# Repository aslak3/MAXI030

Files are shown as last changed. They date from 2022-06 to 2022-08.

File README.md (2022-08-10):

# MAXI030: a MC68030 based expandable computer

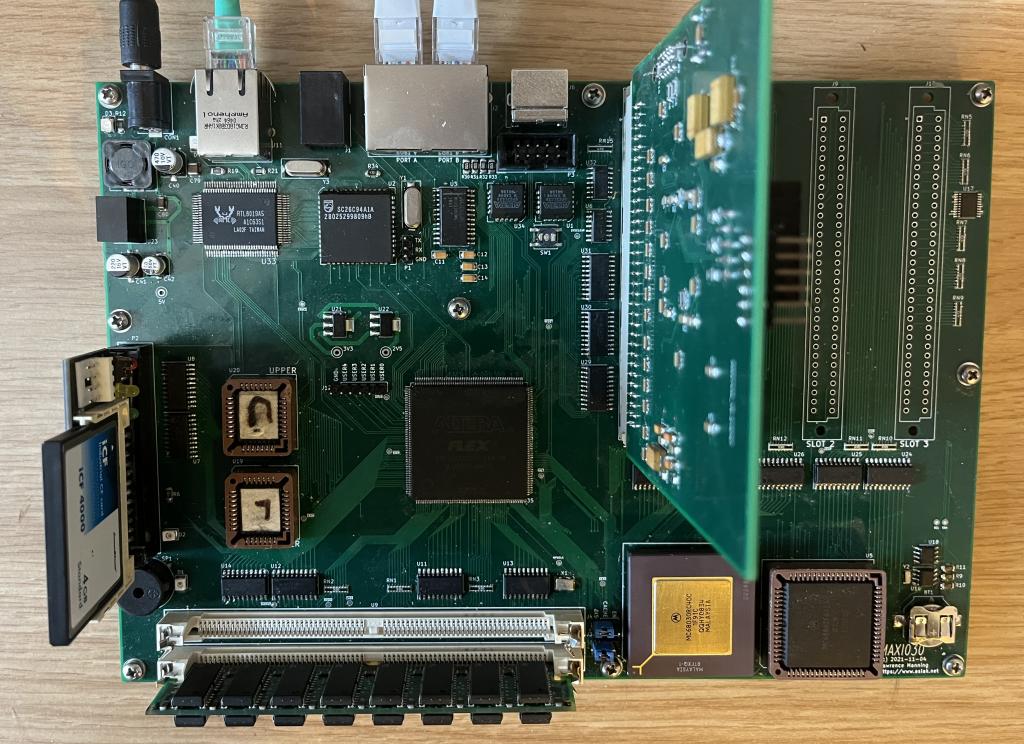
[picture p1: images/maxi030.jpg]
MAXI030 PCB


## Features as currently implemented

The specification for MAXI030, a [MC68030](https://www.nxp.com/docs/en/reference-manual/MC68030UM.pdf) based computer, is as follows:

* A core "glue" that is wired to [master](https://en.wikipedia.org/wiki/Bus_mastering) the 32 bit busses
* Glue is provided by an [EPF10K130EQC240-1](https://www.micro-semiconductor.com/datasheet/12-EPF10K100EFC256-2AA.pdf) FPGA
* A 68030 coupled with a [68882](https://www.nxp.com/docs/en/data-sheet/BR509.pdf)
* 512K x 16 flashes in the form of 2 x [SST39SF040](http://ww1.microchip.com/downloads/en/DeviceDoc/20005022C.pdf) in PLCC32
* 2 x [72 pin SIMM](https://en.wikipedia.org/wiki/SIMM#72-pin_SIMMs) slots with a controller implemented in the FPGA
* A [SC26C94](https://pdf.dzsc.com/6C9/SC26C94.pdf) QUART with the following arrangements of the four serial ports:
  * Two on RJ45 at RS-232 levels following the standard Cisco pinnout
  * One for [my Amiga 600 keyboard](https://www.aslak.net/index.php/amiga-600-avr-based-keyboard-controller/) on an RJ11
  * And a TTL header for debug and the bring-up
* Onboard 10Mbit/s Ethernet using a [RTL8019AS](http://www.ethernut.de/pdf/8019asds.pdf)
* A [PS/2](https://en.wikipedia.org/wiki/PS/2_port) port for keyboard and mouse using a splitter cable
* Four 16 bit wide by 16 MByte deep expansion slots compatible with cards like my [video card](https://www.aslak.net/index.php/2021/07/08/the-design-of-a-video-and-sound-card-for-midi020/) which was implemented for my earlier MC68020 board
* I2C bus with:
  * [DS13057](https://datasheets.maximintegrated.com/en/ds/DS1307.pdf) RTC
  * [LM75A](https://www.nxp.com/docs/en/data-sheet/LM75A.pdf) temperature sensor
  * [PCA9544APW](https://www.nxp.com/docs/en/data-sheet/PCA9544A.pdf) four way expansion slot bus multiplexer allowing expansion cards to attach to the I2C bus
* [IDE](https://en.wikipedia.org/wiki/Parallel_ATA) with DMA signals routed to the FPGA, though they are currently not utilised
* A [P7805-2000-S](https://www.mouser.co.uk/datasheet/2/670/p78_2000_s-1729053.pdf) 2A 5V potted switching regulator attached to a barrel jack

A [schematic](MAXI030.pdf) is included here, along with the [KiCAD](https://www.kicad.org) data files. Note that schematic symbols are included in the library cache. Whilst these boards were designed with KiCAD 4, the files in this repository are all KiCAD 6 format.

## PCB design

The PCB is a 4 layer board. The requirements to make the board are quite heavy; 6 mil traces are used, with 6.5 mil clearances between them. 3 traces pass between 100mil spaced pins in multiple places. My boards were manufactured by [JLCPCB](https://www.jlcpcb.com) with no issues.

## Glue logic core

A major feature of this board is the EPF10K130EQC240 FPGA. This component is part of Altera's [Flex 10KE](https://www.micro-semiconductor.com/datasheet/12-EPF10K100EFC256-2AA.pdf) family, which is a 3.3V/2.5V part descended from the [Flex 10K](https://www.dexsilicium.com/altera_flex_epf10k.pdf) line of 5V parts. These FPGAs are unfortunately obsolete, and difficult to get hold of; I sourced mine from [UTSource](https://www.utsource.net).

The board uses mixed 3.3V and 5V signaling. The Flex 10KE series is "special" in that it is fully 5V tolerant without an inline resistor, unlike later Altera parts such as the early Cylcones which are 5V tolerant but need an inline resistor. The Flex 10KE also have outputs compatible with 5V TTL levels. My previous projects have made heavy use of the 5V Flex 10K parts, but I have found that as the board frequency has increased, these FPGAs have reached their limit. Consequently this board switched to the Flex 10KE, despite the complexities inherent in a mixed signal level board.

Beside getting hold of the actual part a challenge facing anyone building this board is obtaining a compatible Altera Quartus version since Intel have, in their wisdom, removed from their site the 9.0sp2 version; the last that supported the Flex 10K(E) series. It can still be obtained if you know where to look, however.

Another small annoyance, related to the FPGA side of the board, is that two EPC2 configuration flashes are needed since this is a large, for the time, FPGA.

I have implemented the following functionality, all in VHDL:

* Core glue, address decoding etc
* A basic DRAM controller for one of the SIMM slots
* Buzzer and LED driver
* Simplistic interrupt routing (autovectored only for now)
* An I2C master to operate the RTC and temperature sensor
* A PS/2 controller for both PS/2 connections
* An SPI output channel, and bi-directional UART, both for debugging

The code for this functionality resides in the [MAXI030Core directory](MAXI030Core), where a more detailed description of the files used can be found.

As this is FPGA hardware, many other things could be implemented. In particular, the FPGA is wired to the full 32 bits of address and data, so a bus-mastering DMA controller could be constructed. This could be used for disk transfers, amongst other things, which would greatly speed up these operations. The interrupt handling is also basic at present, and vectored interrupts should probably be used.

It's worth pointing out, for completeness, that since the FPGA is attached to a 32 bit wide by 4GB address space it would theoretically be possible to use this board to replace the 68030 with some other custom softcore processor running inside the FPGA, with the 68030 disabled or simply not present. Perhaps a more interesting opportunity would be to implement a custom 68020+ style co-processor.

## Expansion Cards

The following three cards have been created:

1. [TestSRAM](ExpansionCards/TestSRAM/) - This is card is only really useful for the bringup. It has two 512KB SRAMs attached, along with pin headers attached to he expansion bus. It allows the system to be used without having a SIMM attached (and working).
2. [Printer+Sticks](ExpansionCards/Printer%2BSticks/) - This is a fairly simple card featuring a [MC68230](http://www.ceipsa.com/datasheet/MC68230.pdf) and some latches. The board does not feature a DB25 connector, instead the printer must be attached through a "standard" 2x13 PC style adapter. The latches are attached to DB9 Atari-style joystick ports.
3. [Video+Sound](ExpansionCards/Video%2BSound/) - The most interesting card by far; this a VGA card implemented with a Cyclone II FPGA and some fast 16 bit SRAM to hold the video framebuffer. Also featured is an I2S DAC.

The TestxSRAM card (such as it is) has been shown to be error-free. The Printer+Joystick card has been exercised by attaching an old 9 pin dot matrix printer and printing text, though this was with the earlier MIDI020 68020 board. The Video+Sound board has been attached to MAXI030 and, though it has a few teaming troubles, it appears to work well. The sound portion of that card has not been explored at all however.

More documentation on these cards will be forthcoming. For now, each expansion card directory contains the schematic and PCB files in KiCAD format, plus a PDF of the schematic, the BOM, and the rendered gerbers used to produce the cards.

## Machine-code monitor

Over the years I've extended my monitor to run on each 68K based board as I've produced them. The monitor is basic, but serviceable. It is in no way designed for software development; it's main purpose is to exercise the hardware. It has low-level (memory/IO operations) and high level functionality:

* IDE identify, read and write sectors
* PS/2 reading/writing
* I2C reading/writing
* And others

It is also used to start the Linux kernel.

The monitor source is held in its [own repository](https://www.github.com/aslak3/m68k-monitor).

## Linux

A Linux port has been started and seems to work quite well. The following hardware has been shown to work, by making very small changes to existing drivers or creating new ones:

* /dev/ttySC{0,1} UART ports - these map to Port A and Port B on the board
* IDE - though neither interrupt mode or DMA is currently supported so it is rather slow
* Ethernet - works well, though the transfers are on an 8 bit port
* RTC and temperature sensor - an I2C bus driver has been produced which can talk to these peripherals
* PS/2 - the driver implemented supports both ports
* Framebuffer - a very slow and Work in Progress driver for the video card I've built

With a 32MHz can installed, a modern Linux kernel will boot in about 2.5 minutes. But see the Gotchas section below.

A [fork of the Linux kernel](https://www.github.com/aslak3/linux.git) from early 2022 has work done at the head of the lm/maxi030 branch with the changes I've made.

The userland I'm currently using is based on a very old Debian build, even though the kernel is almost the latest, since running the latest 68k Debian packages results in a very slow system. This is another thing to investigate.

A script, which is a total hack, for generating an directory tree of Debian Linux is available in the [linux](linux) directory. This script can generate both sid (current) and sarge (old) Debian images. It must be edited before use to set the DNS resolver, interface addressing, passwords, custom packages and other things. It makes use of [multistrap](https://wiki.debian.org/Multistrap) and [QEUMU's 68K support](https://wiki.qemu.org/Documentation/Platforms/m68k) to do its thing.

As it currently stands, the Linux system is useable across the UART (via a login getty), and via the network. Both SSH and telnet are available, SSH being extremely slow as predicted. Console access, using the PS/2 port and my bitmap video card, is very much a work in progress, though I did have X running (very, very slowly) at one point.

The general process to get Linux running on MAXI030 is as follows, assuming the board is up and running with the monitor available via a UART port:

1. At present the MAC address of the Linux host, which will supply the image, is hardcoded into the monitor program in ne2k.c in the ne2k_transmit subroutine; change it to your PCs MAC address. Note that the MAXI030 MAC address is hardcoded to 11:22:33:44:55:66
2. Build a suitably patched kernel and convert it to a raw image
3. Modify the eth-sender program as required, at a minimum the device name for the connected ethernet interface is hardcoded
4. Run up the eth-sender program (it requires root), the kernel should be available in the same directory and called vmlinux.bin
5. Partition a Compact Flash: two partitions using MBR, partition 1 for swap and 2 for the rootfs in ext3 (ext4 will work with a newer Debian userland)
6. Modify the make-multistrap script as required
7. Create the Debian directory structure and copy it into partition two on the Compact Flash
8. Create a swap partition (mkswap) on partition one
9. Plug in the Compact Flash and turn on MAXI030
10. Transfer the kernel to MAXI030 with the linuxdl command
11. Run the kernel with a monitor command like: linuxrun "console=ttySC0,38400 root=/dev/sda2"
12. Wait for kernel to boot
13. Login via the getty, test the network etc

## Issues

The big issue I'm currently working on is board speed. With all the functionality enabled in the FPGA design, I'm currently not able to run the board at the maximum speed of the 68030 I have installed, 40MHz. Insteaed I must settle for running the board at 32MHz. In particular adding the FIFOs on the PS/2 controller results in an inoperable system at 40MHz. The FIFOs seem to be required when running in Linux since the kernel disables interrupts in some situations, which results in data loss.

The board also has a few very minor problems:

* The switching regulator footprint matches the 1A [SR10S05](https://www.xppower.com/portals/0/pdfs/SF_SR.pdf) and similar; the original 2A part fits but must hang off the board since its pinout is reversed. In use and with the video card inserted and a single SIMM attached I've rarely seen the current draw pass 500mA so I think a 1A regulator will be fine
* The silk screen labels for UART Port A and Port B are the wrong way around
* The labels for Enable/Disable on the MMU/cache jumpers are also backwards

## Blog

The best place to learn about this board is undoubtably [my blog](https://www.aslak.net/index.php/category/68k/), including these posts:

* [The design of MAXI030](https://www.aslak.net/index.php/2021/10/02/the-design-of-a-68030-based-expandable-computer/)
* [Porting Linux to the MAXI030](https://www.aslak.net/index.php/2022/01/11/porting-linux-to-the-68030-based-maxi030/)

I've also made a [short YouTube video](https://www.youtube.com/watch?v=WL3ttsiriho), which discusses the board and demos the Linux port.

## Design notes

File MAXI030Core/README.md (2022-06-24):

# MAXI030Core

The MAXI030 FPGA is responsible for essentially all the functionality that would have traditionally been included in glue logic, wether implemented with discrete logic ICs, GALs, or whatever. It also contains the logic for implementing various controllers and interfaces, which would normally be handled by external peripheral ICs, including:

* DRAM controller for the SIMM slots, including the address multiplexers
* I2C master
* PS/2 interfaces (for keyboard and mouse)
* Interrupt control
* LED and buzzer output control
* 5 pins of user-headers, generally used for debugging and board bringup

Since the FPGA is attached to the full 32 bits of the address and data busses, it is eventually intended to implement a bus-mastering DMA controller, though no progress has been made to this end.

The design also includes a debug/bringup aid in the form of an SPI output-only interface.

Currently only the top 8 bits of databus are used for communication between the processor and the FPGA. This is a result of this design being an evolution of an earlier one where this was a wiring restriction. Consequently services which require larger values to be programmed into them, like the timer, require multiple addresses. This will be eliminated when the full 32 bit databus is utilised.

Note that for consistency all internal signals use positive logic. Inputs are converted to positive logic and outputs are converted to negative logic, if needed. The n_ prefix on signal names is used to indicate negative logic.

Please note that I'm a self-taught VHDL designer. Except in rare cases, these designs do not make use of test benches.

## maxi030_core.vhd

This is the main design file and includes the following entities:

### vector_mapper

This entity deals with startup. Like most 68K based boards, a "trick" is used to map the ROM/flash into low memory only for the initial startup. After the initial Stack Pointer and Program Counter (2 longs, which needs 4 accesses to the 16 bit wide ROM) have been read in, the system enters the normal runtime mode where address decoding will utilise the runtime address map, which is described below. This is achieved by counting (with a shift register) Address Strobes edges; after 4 rising edges the vectors have been read and the system is in the normal runtime mode, indicated by a high vector_fetched output.

### addr_decode

This is the main address decoding logic. Due to various factors, this is currently implemented as a sequential block instead of the more obvious and likely correct combinational design. Partly this is because of the complexity in the memory map for the system. A combinational decoder would be very hard to write "nicely".

The address map is as follows, all addresses in hex. Note that the decoding is partial in that the selected devices will appear at many addresses not just the "official" address used by software. This saves logic resouces. Don't cares are illustrated by dashes in the table below:

<table>
<tr>
<th>Address</th>
<th>Function</th>
</tr><tr>
<td>00000000-30000000</td>
<td>SIMM slot 0</td>
</tr><tr>
<td>40000000-40ffffff</td>
<td>Expansion slot 0</td>
</tr><tr>
<td>41000000-41ffffff</td>
<td>Expansion slot 1</td>
</tr><tr>
<td>42000000-42ffffff</td>
<td>Expansion slot 2</td>
</tr><tr>
<td>43000000-43ffffff</td>
<td>Expansion slot 3</td>
</tr><tr>
<td>44--0---</td>
<td>FPGA registers</td>
</tr><tr>
<td>44--0-00</td>
<td>LED</td>
</tr><tr>
<td>44--0-01</td>
<td>BUZZER</td>
</tr><tr>
<td>44--0-02</td>
<td>SYS_CONFIG</td>
</tr><tr>
<td>44--0-03</td>
<td>PS2A_STATUS</td>
</tr><tr>
<td>44--0-04</td>
<td>PS2A_SCANCODE</td>
</tr><tr>
<td>44--0-05</td>
<td>PS2B_STATUS</td>
</tr><tr>
<td>44--0-06</td>
<td>PS2B_SCANCODE</td>
</tr><tr>
<td>44--0-07</td>
<td>I2C_ADDRESS</td>
</tr><tr>
<td>44--0-08</td>
<td>I2C_WRITE_DATA</td>
</tr><tr>
<td>44--0-09</td>
<td>I2C_READ_DATA</td>
</tr><tr>
<td>44--0-0a</td>
<td>I2C_CONTROL</td>
</tr><tr>
<td>44--0-0B</td>
<td>RTC_INT_CONTROL</td>
</tr><tr>
<td>44--0-0c</td>
<td>SPI</td>
</tr><tr>
<td>44--0-0d</td>
<td>TIMER_COUNTU</td>
</tr><tr>
<td>44--0-0e</td>
<td>TIMER_COUNTM</td>
</tr><tr>
<td>44--0-0f</td>
<td>TIMER_COUNTL</td>
</tr><tr>
<td>44--0-10</td>
<td>TIMER_CONTROL</td>
</tr><tr>
<td>44--0-11</td>
<td>INT_PASS</td>
</tr><tr>
<td>44--1---</td>
<td>QUART</td>
</tr><tr>
<td>44--2---</td>
<td>IDE1</td>
</tr><tr>
<td>44--3---</td>
<td>IDE3</td>
</tr><tr>
<td>44--4---</td>
<td>ETH</td>
</tr><tr>
<td>ff------</td>
<td>ROM</td>
</tr><tr>
</table>

The address decoder also deals with non "normal" accesses, namely:

* FPU: The coprocessor uses standard bus cycles, but with a specific Function Code output, and address outputs.
* Interrupt Acknowledgement: Similar to coprocessor access.

When not in the vector_fetched state, the address decoder is also responsible for forcing the ROM to be selected, regardless of other inputs.

Note the overlying state of a bus cycle, which is one of:

* CYCLE_NULL: set when the address strobe is not asserted
* CYCLE_BOOT_VECTORS: set for the first four address strobe cycles
* CYCLE_FPU: set when the cycle is an FPU cycle
* CYCLE_INT_ACK: set when the cycle is an interrupt acknowledgement
* CYCLE_REG: set when an FPGA register is being accessed
* CYCLE_NORMAL: set for all other accesses

This is asserted combinationally in the external entity, and is fed to the address decoder to save it somme work.

The output of the address decoder is an array, with one element per device. The address decoder will only assert one select at a time. Another key signal the address decoder is responsible for generating is the addr_width output, which sets the width of the device selected (byte, word or long). This in turn is used to generate the processor's /DSACK signals. For instance, the SIMM is a 32 bit (long) wide device, whilst the flash and expansion slots are 16 bits wide.

The following is a table for the data width of the various devices on the board:

<table>
<tr>
<th>Device</th>
<th>Width</th>
</tr><tr>
<td>SIMM</td>
<td>Long</td>
</tr><tr>
<td>ROM</td>
<td>Word</td>
</tr><tr>
<td>Expansion slots</td>
<td>Word</td>
</tr><tr>
<td>RTL8019AS (NIC)</td>
<td>Word</td>
</tr><tr>
<td>IDE</td>
<td>Word</td>
</tr><tr>
<td>QUART</td>
<td>Byte</td>
</tr><tr>
<td>Core registers</td>
<td>Byte</td>
</tr>
</table>

## dtack_generator

This entity's job is to delay the /DSACK signal for the number of cycles required for each particular device that needs this functionality. It is is fed a generic; the cycle count. A simple counter is used to assert a "wait complete" signal when the counter reaches the delay value. An instance of this entity is created for each device which needs waitstates. This is one of the few entities to have multiple instances.

## buzzer_generator

A simple tone generator. The tone to be played is generated by incrementing a counter until it reaches the programmed value, upon which the buzzer output is toggled. The upper 8 bits of the 18 bit counter are compared, to scale the tone to audible values. Setting the programmed value to zero disables forces the buzzer output low, silencing the buzzer.

## maxi030_core

This is the top level entity. It is mostly concerned with instantiating the other entities, but also has some functionality of its own.

### Port sizing

The 68030 is a 32 bit processor with a byte addressable address bus. It supports both narrowed (word and byte wide) accesses and unaligned accesses; for example a long read to a word wide port might, in the worst case, be spread across three bus cycles). This is facilitated by the following signals, from the point of view of the processor:

* SIZ{0,1} outputs: This encodes the size of the request.
* A0 and A1 outputs: This indicates the offset into the word or long.
* /DSACK{0,1} inputs: This encodes the size of the port available at the selected address, in addition to indicating that the processor should generate an internal waitstate.

To complete the access, the processor may need to generate individual byte selects. For instance, a 32 bit device, like a 72 pin SIMM, needs byte selects for each of the 4 bytes available. These outputs need to be generated based on the size of the request and the A0/A1 values for the access.

Luckily the [MC68030 datasheet](https://www.nxp.com/docs/en/reference-manual/MC68030UM.pdf) includes both a schematic including 74-series logic gates, and some [ABEL](https://en.wikipedia.org/wiki/Advanced_Boolean_Expression_Language) code for a circuit that generates the needed signals for word and long-wide devices. This ABEL code has been translated into VHDL and included verbatim. Devices use these internal signals to form their final chip selects, by combining them with the device selects generated by the address decoder.

### Cycle type generator

This was covered in the address decoding section above.

### Read and Write generator

This is a simple but critical part of the design which generates internal read and write signals, using the /DS data strobe and R/W signal. In this block the write line is also inhibited for ROM access, if the SYS_CONFIG register is configured to do this. This was useful on earlier boards which used simple EEPROMs but is less useful now that flashes, which can only be programmed by very specific command sequences, are used.

### Register Read and Write action

This sequential process is responsible for managing internal state based on accesses by the processor to FPGA-exposed registers. For instance, the board LED is controlled by the processor writing to the low bit of the LED register's address (generally 44000001). This action, and that of the other registers, is handled here.

This block is also responsible for clearing trigger signals which are set for one cycle only after writing to a register. This is the basic mechanism for many parts of the overall design, such as the I2C data sender: writing to the I2C_WRITE_DATA register will both latch the data to be sent, and trigger its sending.

Lastly read accesses are handled here. Most read accesses are "no ops", but some have side effects; for instance reading a PS/2 scancode register will cause the read FIFO to expose the next data item, assuming there is one.

### Presenting data on the databus

The main instance when data must be presented on the FPGA's databus is when FPGA-exposed registers are read, though there are other potential cases, including when interrupt vectors are generated, though this is not currently implemented. This is simple combinational logic: the address decoder output is combined with the general read signal and the databus asserted with the needed value. Note that some registers use the full 8 bits of data, but some will just use the lower bits and set the higher bits to zero.

### Chip Selects and other outputs

Here decoded internal selects are combined with the request sizing signals to generate the external chip selects. For instance the lower ROM IC is enabled when the address decoder selects the ROM and the sizing logic indicates the low half of the a word wide port has been selected. The eight expansion card upper and lower selects are also generated here.

This block also includes the SIMM /RAS and /CAS output generation, from the signals generated from the contoller, as well as the generation of negative logic for other outputs like /READ and /WRITE.

The LED output is set here based on the status of bit 0 of the LED register, which is itself held in the led_state signal, which is set in the register write action process, described above.

### /DSACK generation

/DSACK generation uses a combination of the addr_width signal, generated by the address decoding, and the waitstate generator for each of the devices that require waitstates. If a waitstate is needed both outputs are driven high. If no waitstates are pending then the /DSACK output is set to the size of the selected port. One exceptional case is the FPU, which requires the /DSACK pins on the FPGA to be tristated so that FPU itself can generate the processor's /DSACK inputs.

### Interrupt routing

At the current time interrupt routing is sequential logic, though this is probably incorrect. In any case the interrupt routing is very simplistic: a priority encoder is used based on the interrupt inputs and the interrupt mask bits in the INT_PASS register. Currently 5 bits are defined, one for each of the possible interrupt sources. If a bit is 1, the interrupt can be enabled, if it is 0 it will be blocked. Each priority level maps to an /IPL level.

### Generation of misc MPU signals

Some simple combinational logic is used to generate the /CIIN (Cache Inhibit Input) signal: if the ROM or the SIMM is selected, the cache is enabled (/CIIN is high) otherwise it is disabled. This prevents IO operations from being cached. Currently the bus mastering functionality in the 68030 is not used, so signals related to it are all driven high here.

### SYS_CLEAR signal generation

As an extra precaution for a clean processor startup, the processor (and other devices) /RESET signal is held off being cleared at power on by a counter. This keeps the processor paused while the FPGA configures itself - which is accomplished with a pull-up resistor attached to the input of an open-collector NAND gate, which itself has a pull-up resistor on its output that's attached to the 68030's /RESET input - and for a short time afterwards, using a counter. In theory the counter is not needed, but is present out of paranoia. Note that system reset (but not the FPGA itself, which is only reset as a result of being reconfigured) is under FPGA control. This could allow the implementation of a watchdog timer, and similar functionality, though nothing has so far been written to do this.

## timer.vhd

Though the board's QUART contains two timers, the Linux port required a standalone timer, so one was added to MAXI030Core.

The timer has a 24 bit countdown register (currently exposed on 3 byte wide FPGA-addressable registers) and a control register.

On a trigger, which is set for one cycle when the control register is written to, the current counter value is updated from the starting value and the counter is enabled. At every cycle, if the counter is enabled it counts down. When it reaches 0 the counter rollover output signal is set to 1, but the counter will continue counting down, after being reset to the starting value. Thus no matter how slow the processor is at acknowledging the rollover interrupt, the frequency of the interrupt will match the counter start value.

There are two bits used on the exposed TIMER_CONTROL register:

* bit 0: starts the timer
* bit 1: stops the timer

Clearing the interrupt is achieved by writing a 1 to bit 0, which will restart (though it will still be running) the counter, clearing the rollover output but not otherwise affecting the timer since, at that point, it is already running and not stopped.

## i2c.vhd

The I2C controller used is a direct copy of a project I have published as a [standalone piece of programmable logic](https://github.com/aslak3/i2c-controller). It's interface to the outside world is through the I2C registers. The four byte wide registers are used as follows:

* I2C_ADDRESS : Sets the slave address. The MSB (and not the LSB) is used to set the read (1) or write mode. This will trigger a transfer, sending the address.
* I2C_READ_DATA : This will (somewhat unobviously) trigger a transfer. Poll on bit 0 of I2C_CONTROL until it is 0 to know when the data can actually be read, which will trigger the next transfer at the same time.
* I2C_WRITE_DATA : This will trigger a transfer.
* I2C_CONTROL : This is a read and write register. In read (AKA I2C_STATUS) bit 0 is the busy flag, and bit 1 is the ack_error flag. In write bit 0 indicates that this is the last byte to be transferred.

## ps2_controller.vhd

This is a bi-directional PS/2 interface. As this controller could be useful in other people's projects, this will, eventually, be pushed up into a standalone repository like the I2C controller was, and will be documented fully there.

Note that this FPGA makes use of one Altera "MegaFunction": A FIFO in front of the PS/2 output data. This was added because of problems with missing data bytes from the port when running Linux, presumably because under some conditions Linux will disable interrupts, causing lost data if it is not buffered in hardware.

## simm_controller.vhd

There are two entities which form a fairly dumb DRAM controller, which is used by the SIMM slots (well only one slot currently). A simple state machine is used. Refresh timing is perhaps not completely accurate. Also, the controller does not support EDO mode or rows being held open which would make it more efficient.

However one nice aspect of the design is that because the FPGA is exposed to the entire processor address bus, *and* it is directly attached to the address pins on the SIMM, complete flexibility of supported memory sizes is possible. I currently have access to an 8 MByte and a 32 MByte SIMM, and both have been tested and are working. Note that the mapping of address bits, and thus the size of the supported module, is hardcoded in this file.

This is a particularly interesting area, from the point of view of improvements to the performance of the MAXI030 board: besides the missing EDO mode, it would be great to make use of the MC68030 burst mode to fill the cache with back to back transfers.

## spi.vhd

This is a simple SPI sender. During  bring-up I have used this to capture the state of the processor code execution, by routing the output of this SPI controller to one of the user IO pins and monitoring it with a Logic Analyser. It is normally not used.

## uart.vhd

The MAXI030 board formed a test-bench for a project I have been meaning to tackle for a few years: implementing my own UART. This is about the last of the "old school" serial protocol I have not looked at implementing a controller for, so I thought I would have a go at it. The result is a simple UART interface which has no support for parity and runs at a fixed baud rate. This will be removed from MAXI030Core at some point, since it is not useful as the board contains a nice "hard" QUART IC.

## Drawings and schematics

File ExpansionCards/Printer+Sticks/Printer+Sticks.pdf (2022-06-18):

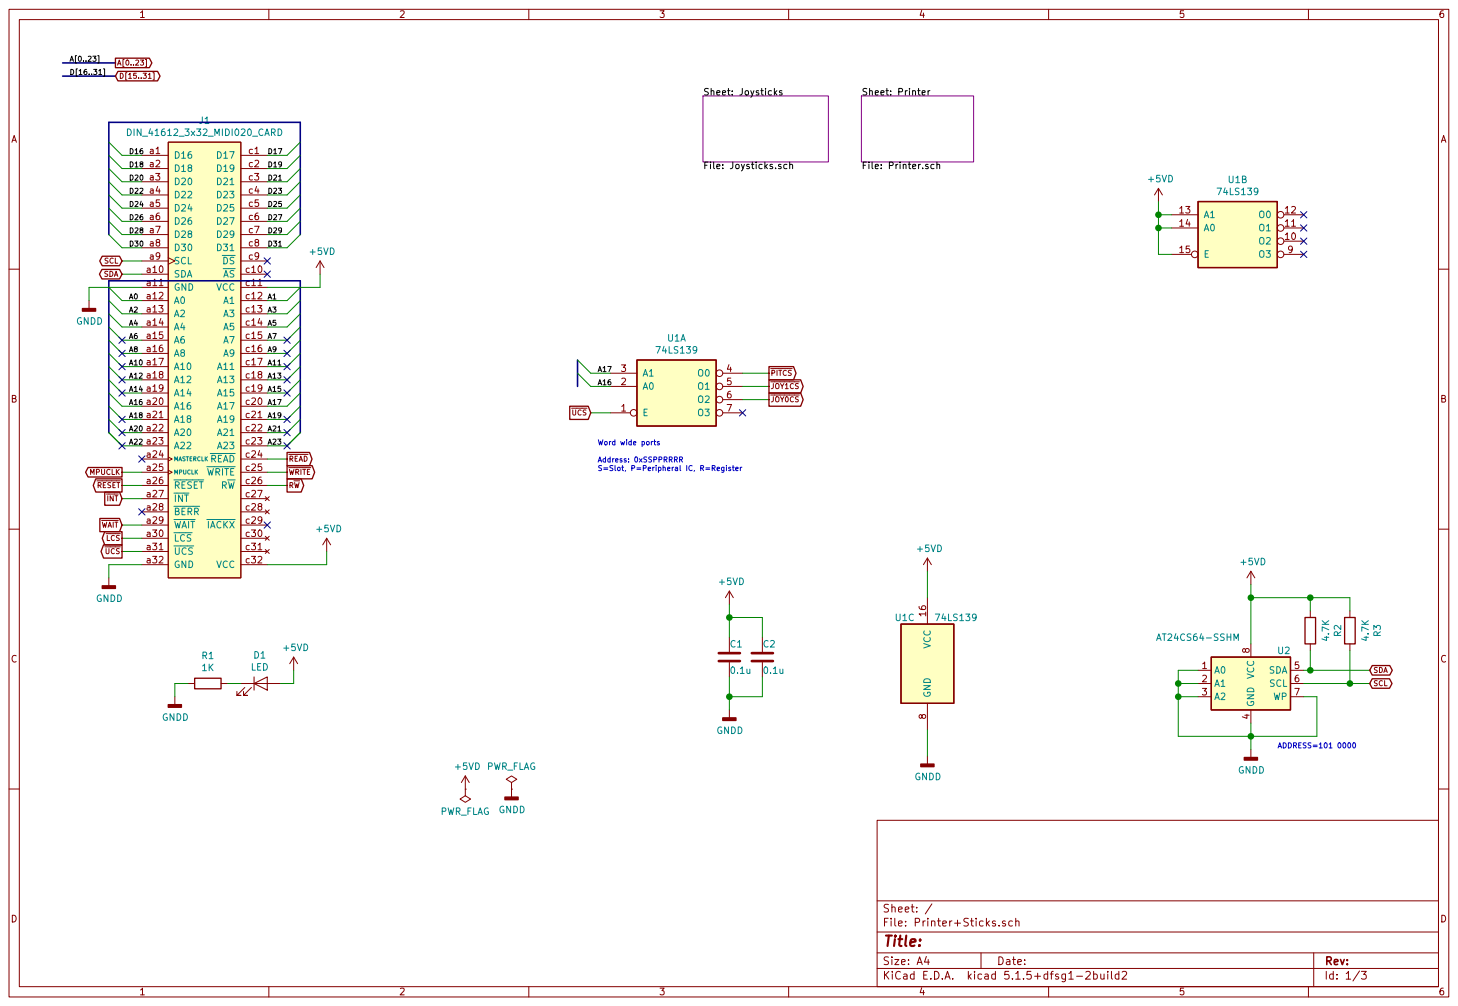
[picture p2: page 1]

LCS WAIT SDA MPUCLK

4 SDA 5 SCL 6 WP 7 VCC

Id: 1/3 Title: File: Printer+Sticks.sch Sheet: /

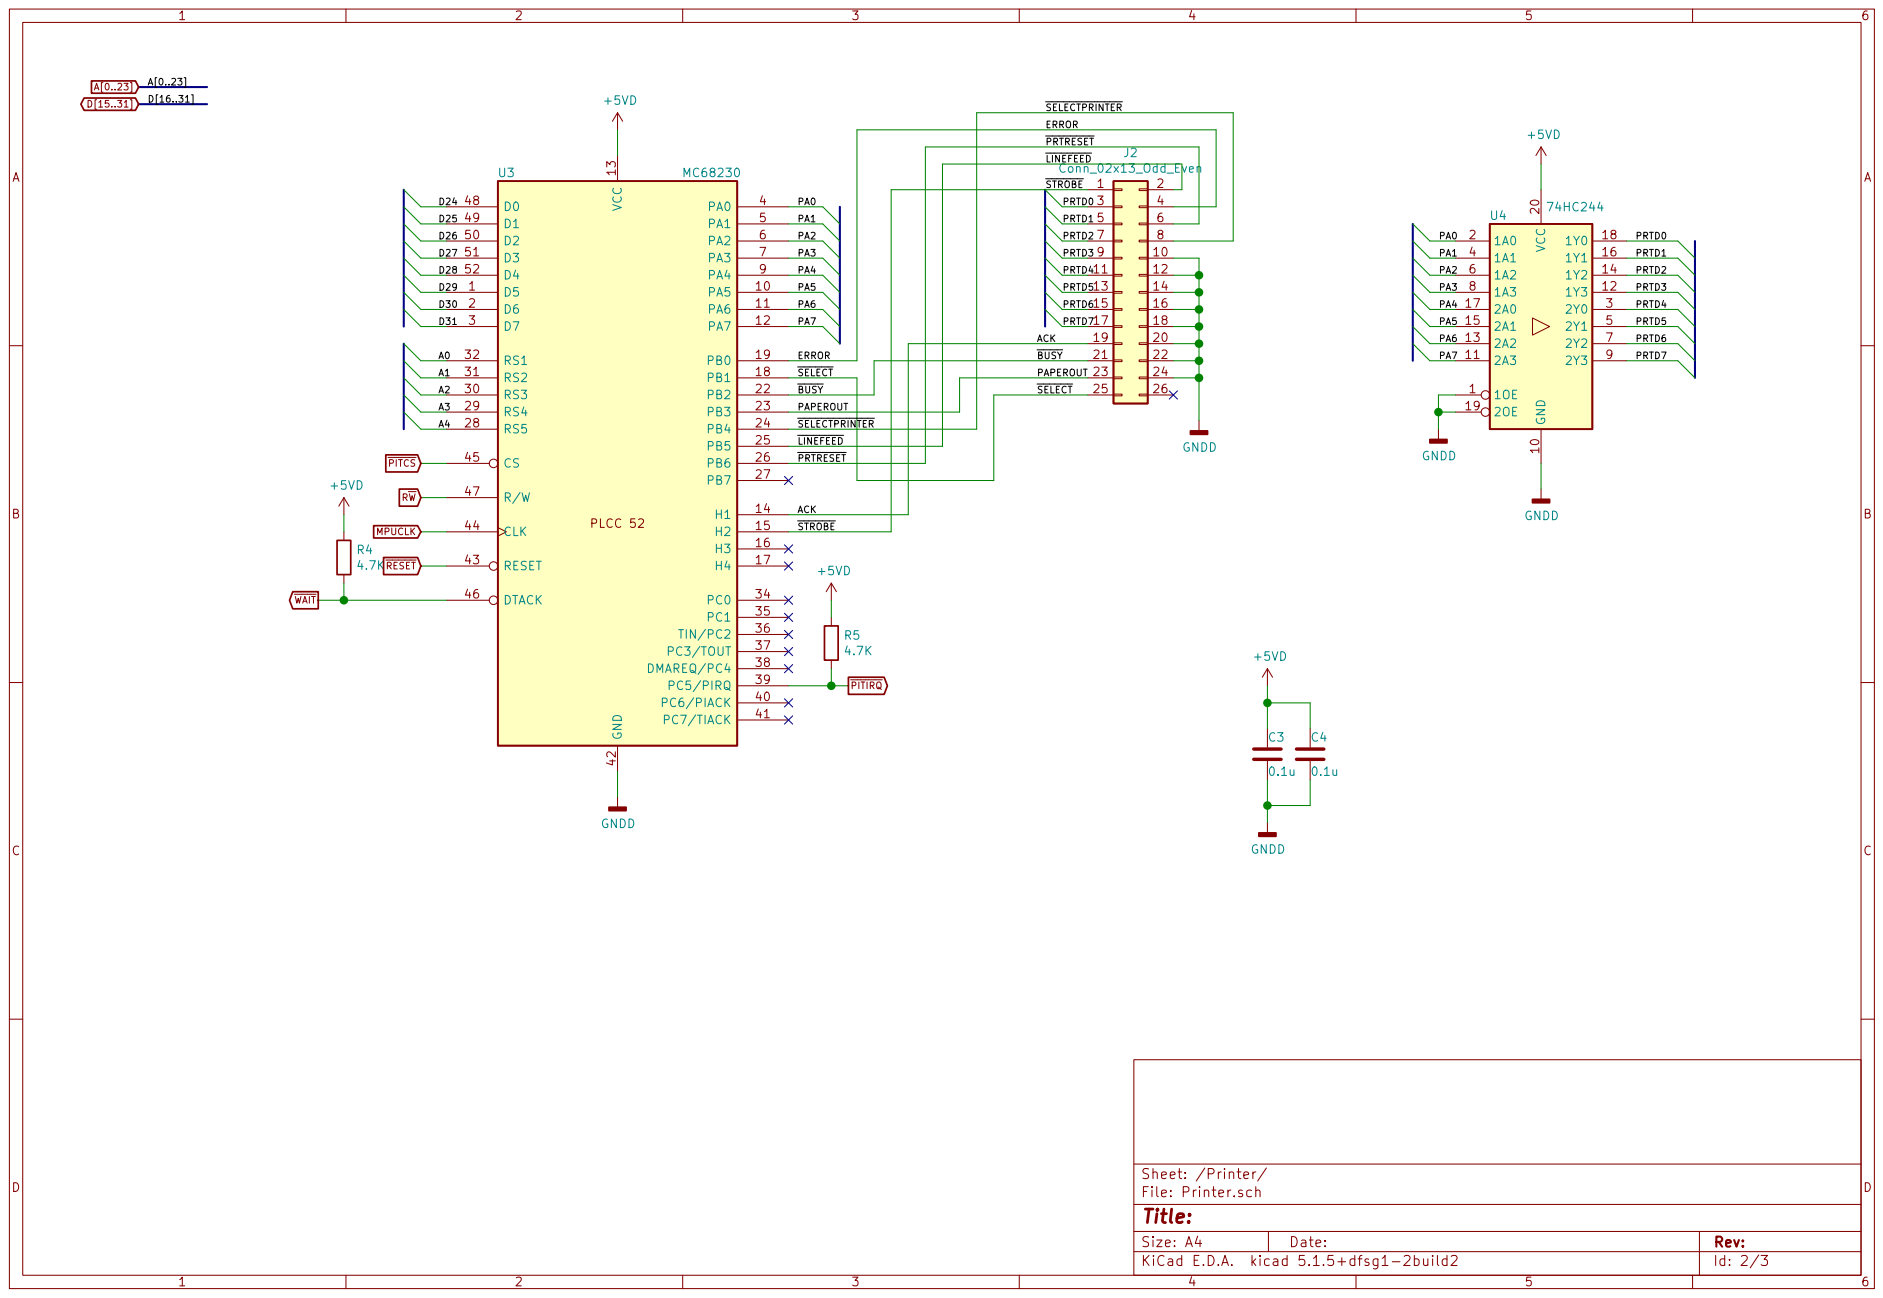
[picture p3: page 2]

PAPEROUT STROBE ACK | 19

SELECT BUSY 23 | 24

PITCS MPUCLK RESET WAIT

Id: 2/3 Title: File: Printer.sch Sheet: /Printer/

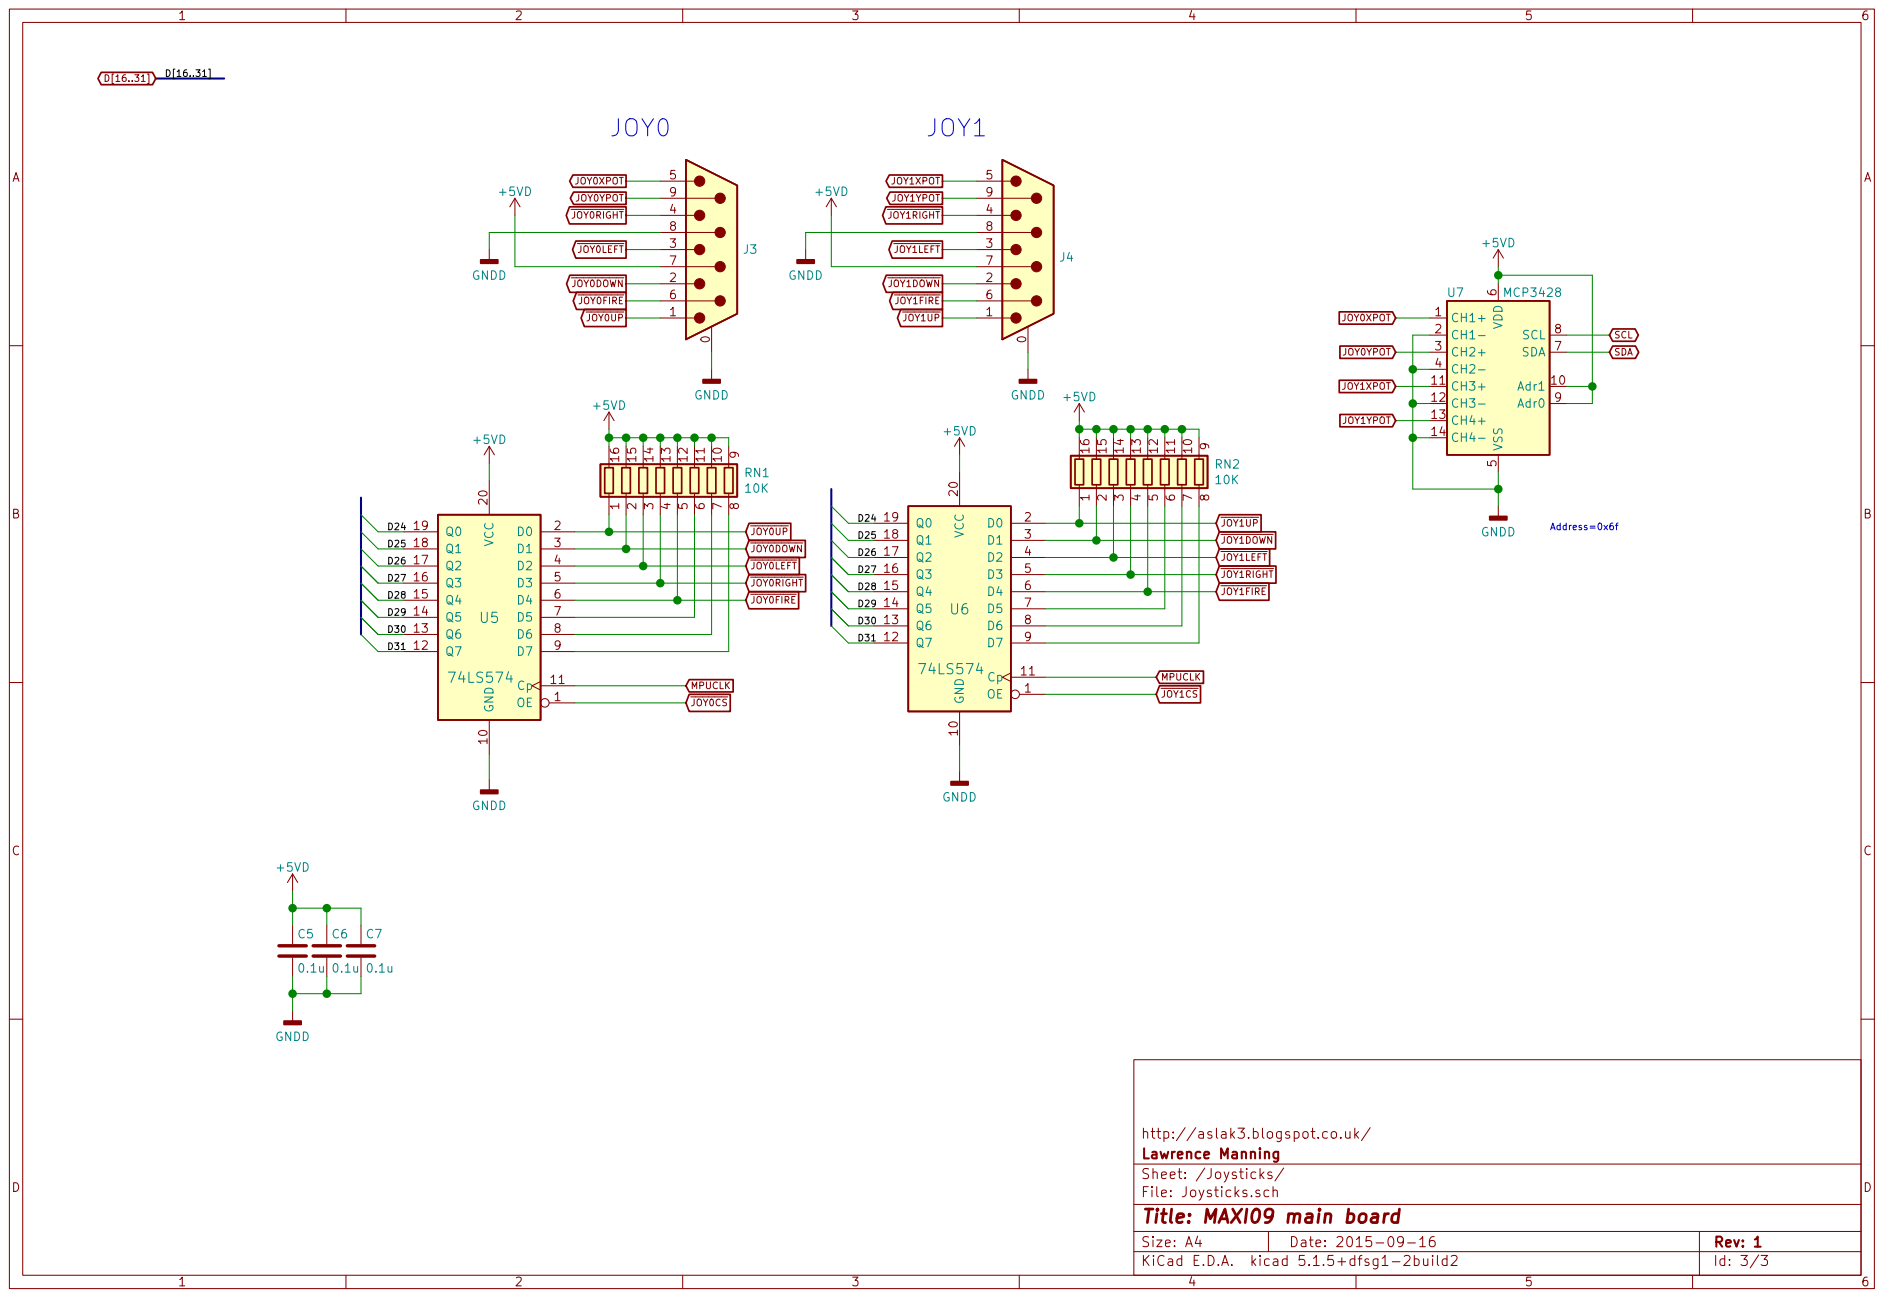
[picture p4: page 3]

http://aslak3.blogspot.co.uk/ C7

Lawrence Manning
Sheet: /Joysticks/
File: Joysticks.sch
Id: 3/3 Title: MAXI09 main board

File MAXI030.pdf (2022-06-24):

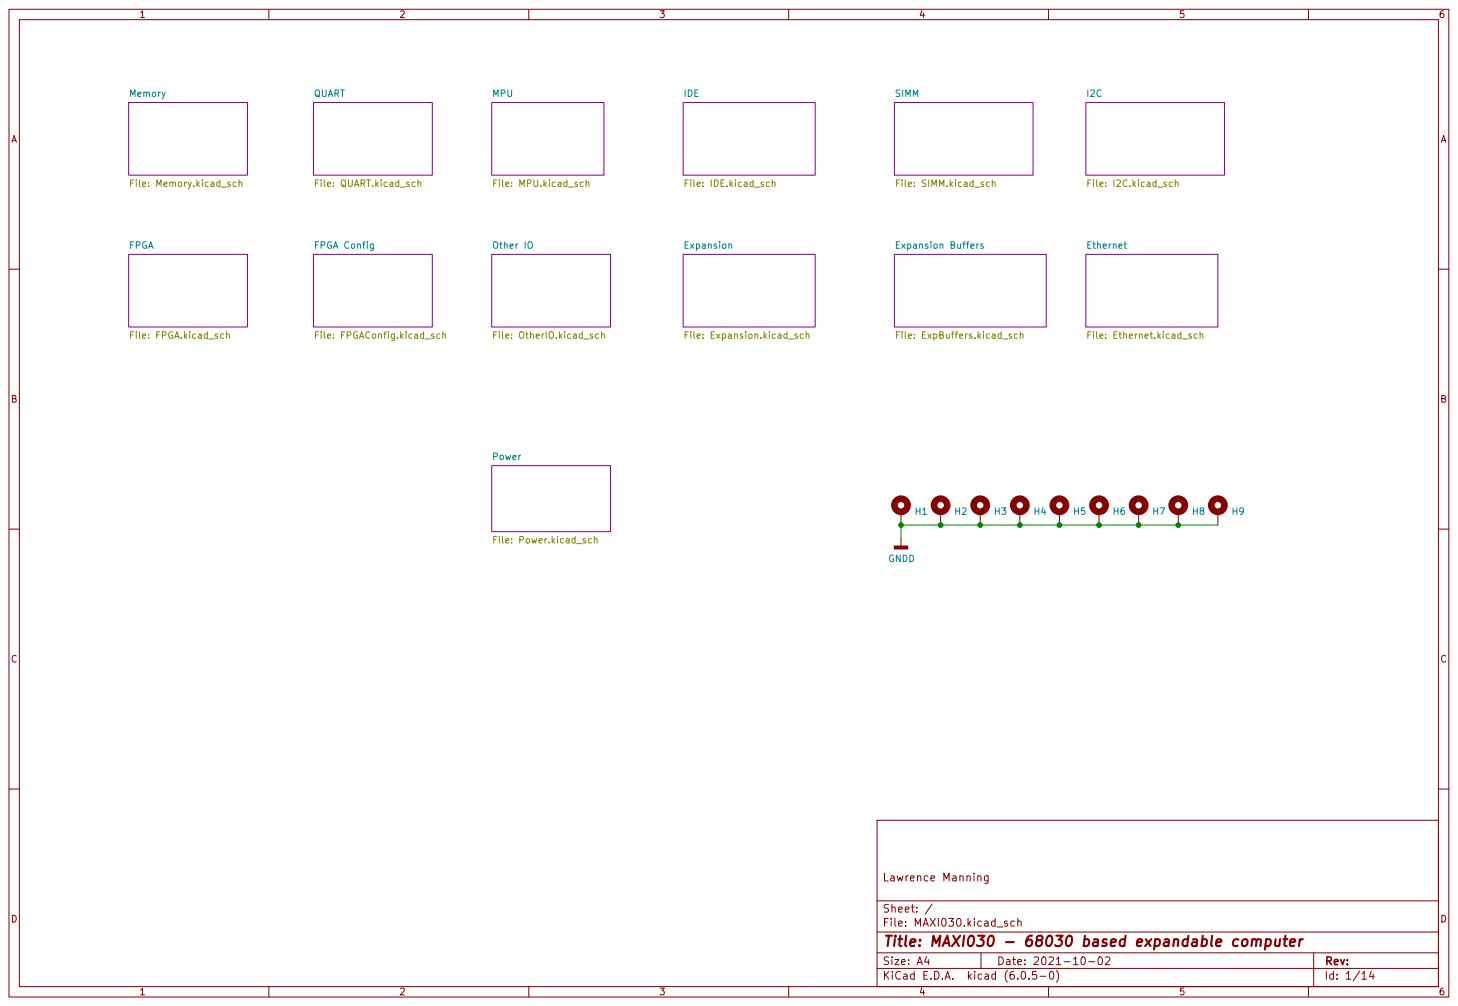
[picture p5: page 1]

File: SIMM.kicad_sch FPGA Config
File: OtherIO.kicad_sch Power File: Power.kicad_sch

File: ExpBuffers.kicad_sch Other IO

File: MAXI030.kicad_sch Sheet: / Lawrence Manning

Id: 1/14 Title: MAXI030 - 68030 based expandable computer

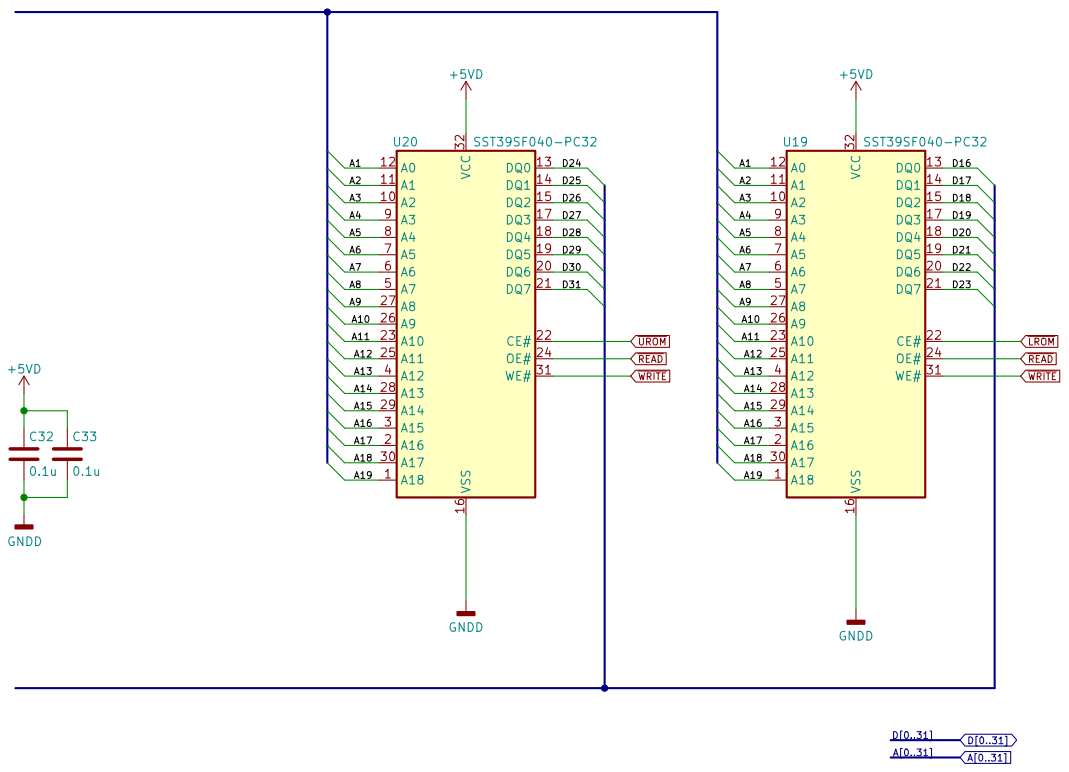
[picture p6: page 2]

Sheet: /Memory/
File: Memory.kicad_sch
Id: 2/14 Title: MAXI030 - 68030 based expandable computer

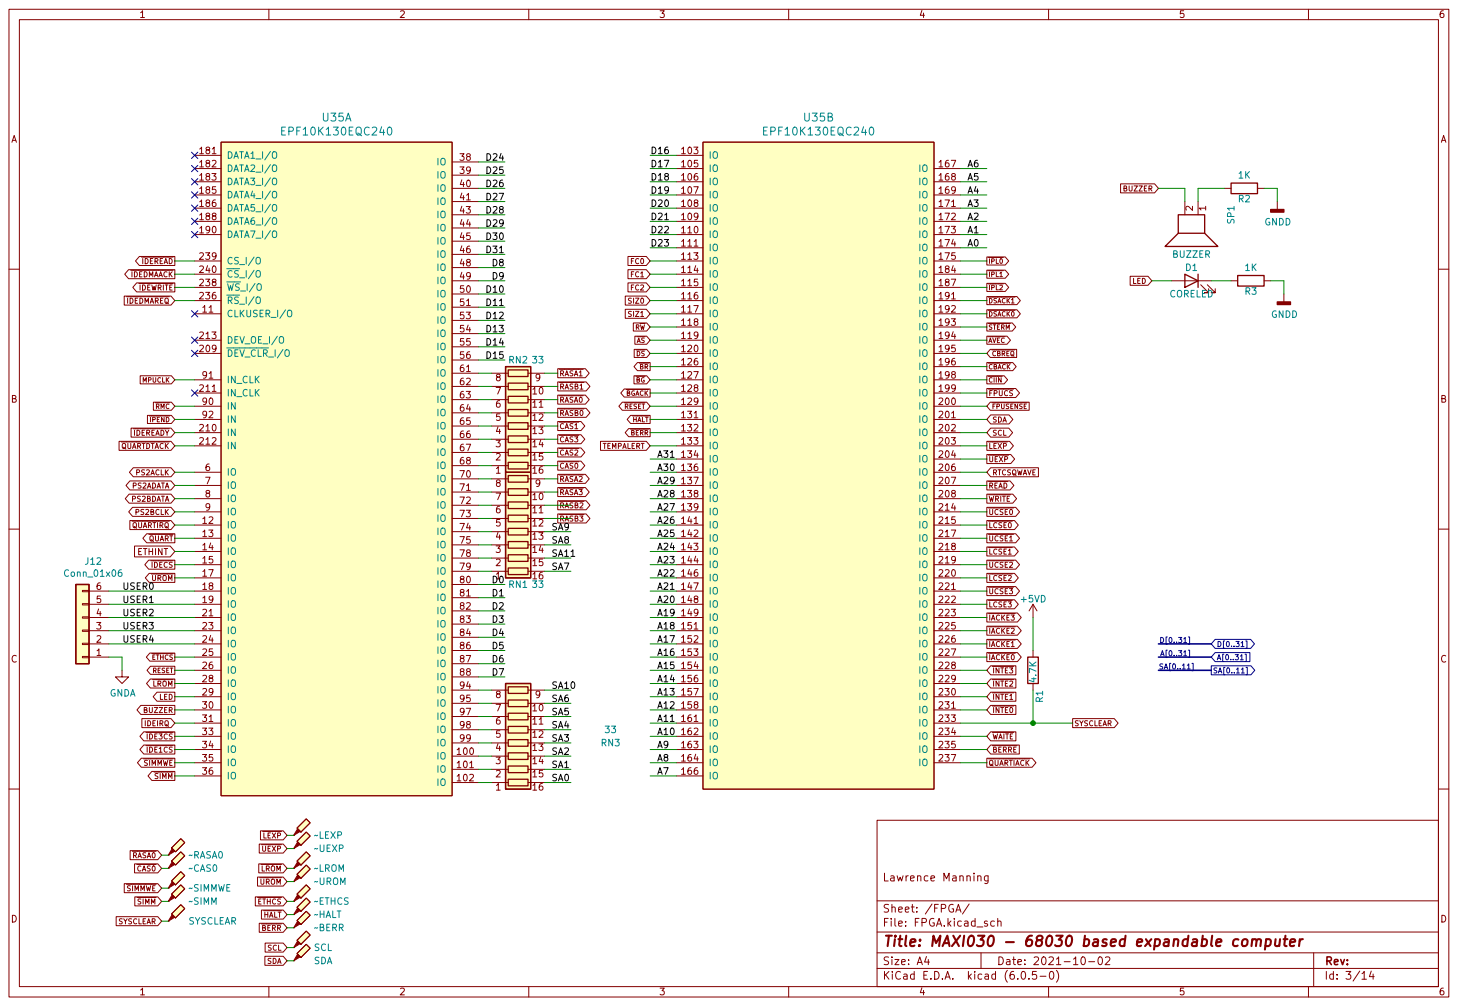
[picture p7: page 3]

~{CBACK} ~{FPUCS} ~{CBREQ} ~{CIIN} ~{FPUSENSE} ~{SIMM} ~{SIMM}

File: FPGA.kicad_sch Sheet: /FPGA/ Lawrence Manning

Id: 3/14 Title: MAXI030 - 68030 based expandable computer

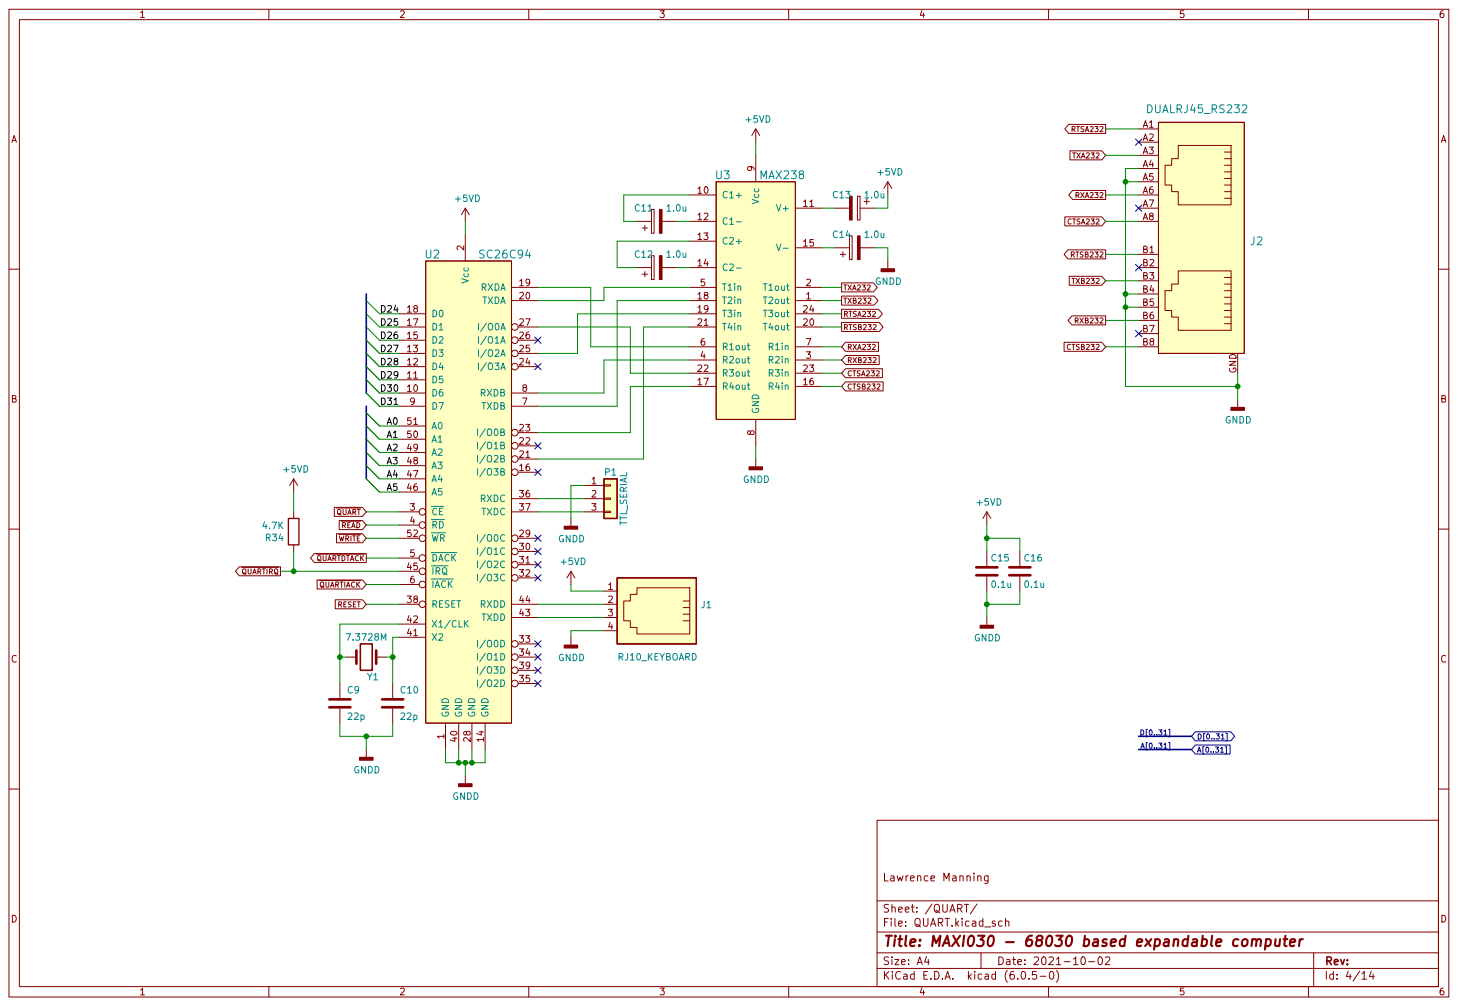
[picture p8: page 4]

Sheet: /QUART/
File: QUART.kicad_sch
Id: 4/14 Title: MAXI030 - 68030 based expandable computer

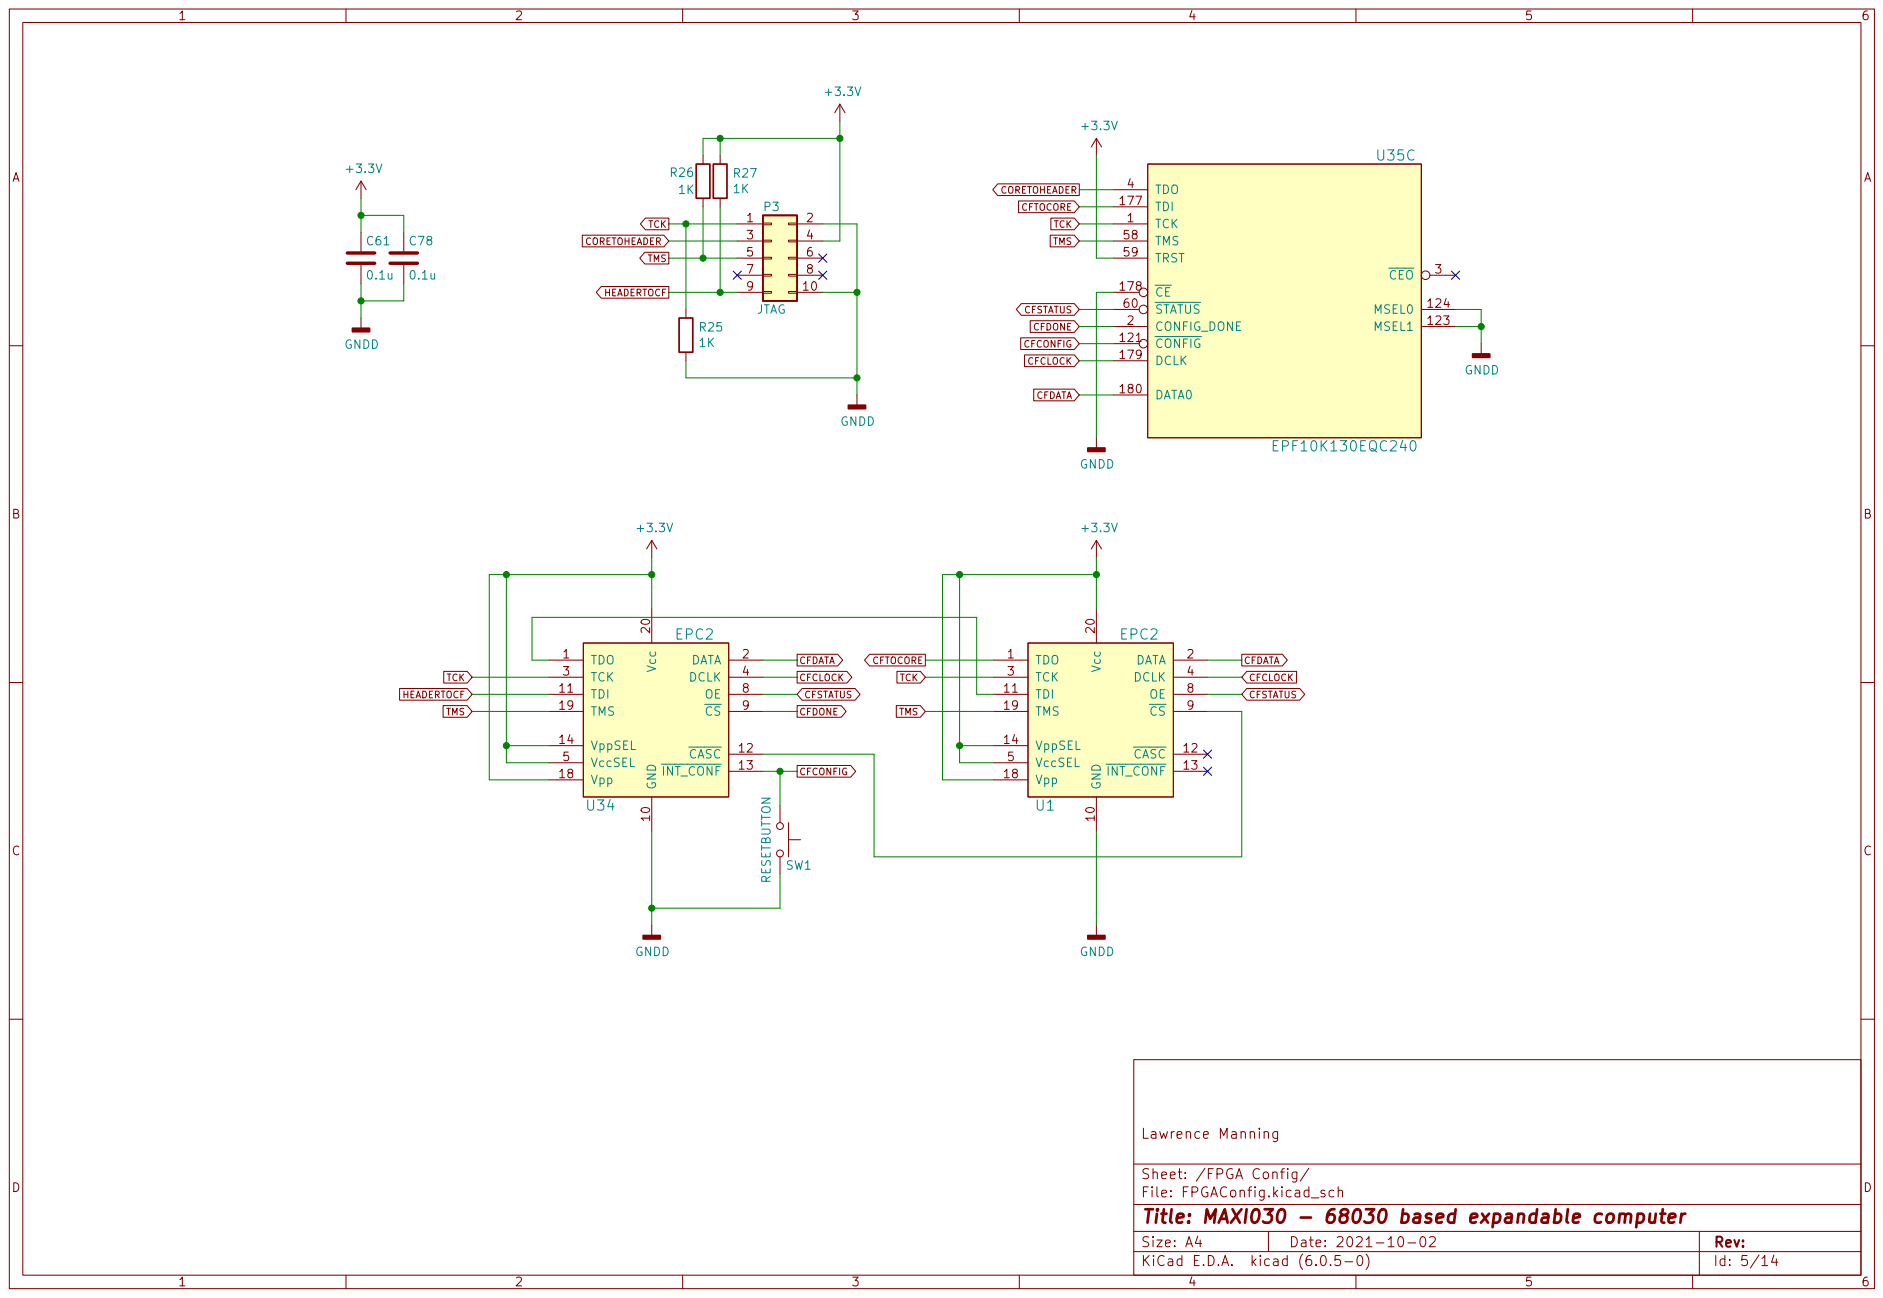
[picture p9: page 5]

TMS CFSTATUS CFDATA CFCLOCK CFCONFIG

Sheet: /FPGA Config/
File: FPGAConfig.kicad_sch
Id: 5/14 Title: MAXI030 - 68030 based expandable computer

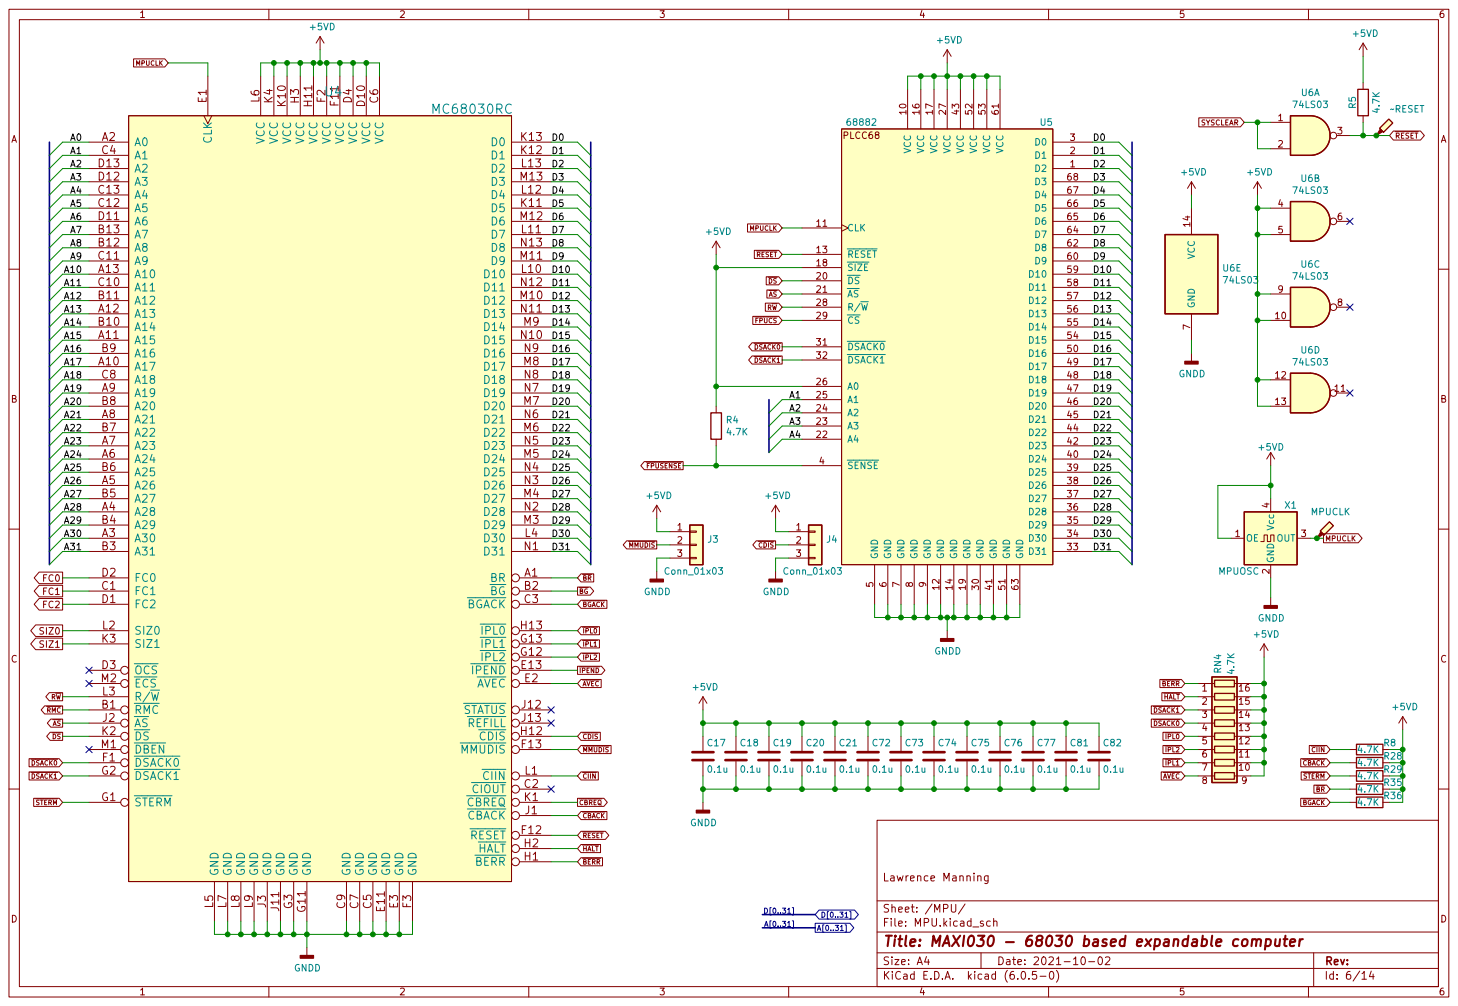
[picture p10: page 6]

5 D16 50 GND 51 VCC 52 VCC 53 D15 54 D14 55 D13 56 D12 57 D11 58 D10 59 GND

2 OUT 3 Vcc 4X1 MPUOSC GNDD

~{CIIN} ~{BGACK} ~{STERM} ~{BR}

File: MPU.kicad_sch Sheet: /MPU/ Lawrence Manning

Id: 6/14 Title: MAXI030 - 68030 based expandable computer

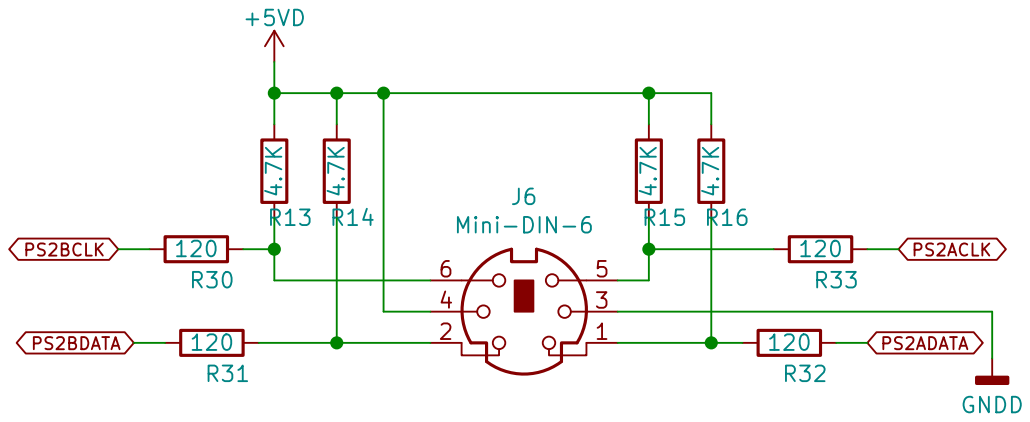
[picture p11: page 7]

File: OtherIO.kicad_sch Sheet: /Other IO/ Lawrence Manning

Id: 7/14 Title: MAXI030 - 68030 based expandable computer

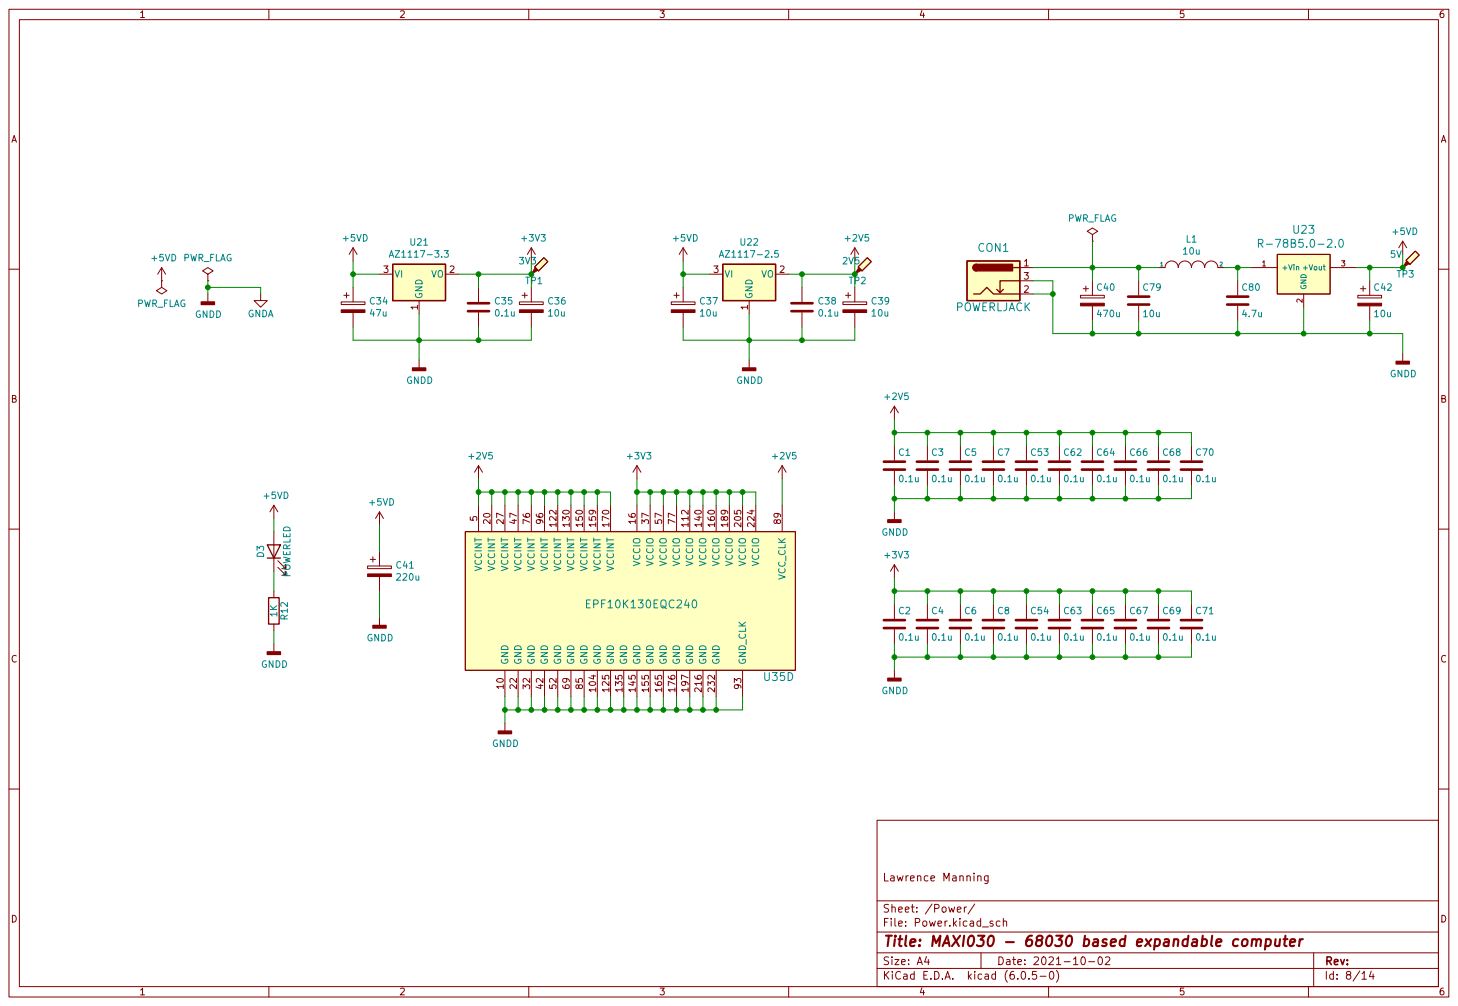
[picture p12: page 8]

5 GND 52 VCCIO 57 GND 69 VCCINT 76 VCCIO 77 GND 85 VCC_CLK 89 GND_CLK 93 VCCINT 96 U35D

Id: 8/14 Title: MAXI030 - 68030 based expandable computer

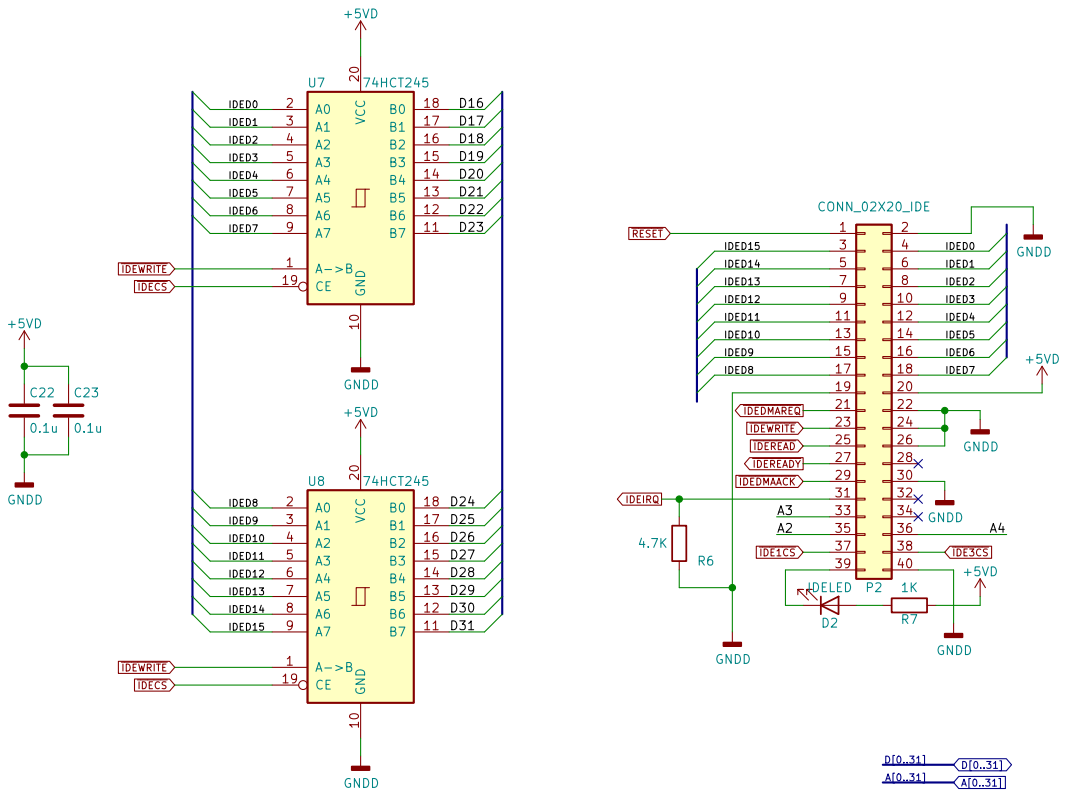
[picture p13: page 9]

File: IDE.kicad_sch Sheet: /IDE/ Lawrence Manning D2

Id: 9/14 Title: MAXI030 - 68030 based expandable computer


Sheet: /Expansion/
File: Expansion.kicad_sch
Id: 10/14 Title: MAXI030 - 68030 based expandable computer


File: SIMM.kicad_sch Sheet: /SIMM/ Lawrence Manning

Id: 11/14 Title: MAXI030 - 68030 based expandable computer


Sheet: /Expansion Buffers/
File: ExpBuffers.kicad_sch
Id: 12/14 Title: MAXI030 - 68030 based expandable computer


4 SDA 5 SCL 6 SQW/OUT 7 VCC

Id: 13/14 Title: MAXI030 - 68030 based expandable computer


File: Ethernet.kicad_sch Sheet: /Ethernet/ Lawrence Manning

Id: 14/14 Title: MAXI030 - 68030 based expandable computer

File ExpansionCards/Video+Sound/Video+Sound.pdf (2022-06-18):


SCL ~{READ} ~{INT} MPUCLK

4 SDA 5 SCL 6 WP 7 VCC

File: Video+Sound.kicad_sch Sheet: /
Id: 1/7 Title:


File: Power.kicad_sch Sheet: /Power/
Id: 2/7 Title:


~{CFGCS} BLUE[0..7] VA[0..19] USERLED

I2SSYSCLKPLL1 ~{VREAD} VA[0..18] RED[0..7] GREEN[0..7] ~{VGABLANK} LMPUCLK

~{LBERR} ~{LUCS} ~{LWAIT} ~{LINT}

2 OUT 3 Vcc 4X1 MASTEROSC GNDD

File: FPGA.kicad_sch Sheet: /FPGA/ Lawrence Manning

Id: 3/7 Title: Video+Sound


4 DATA0/ASDI 5 DCLK 6 Vcc 7 Vcc 8 EPCQnA U2 GNDD

Sheet: /FPGA Configuration/ GNDD


File: VRAM.kicad_sch Sheet: /VRAM and DAC/
Id: 5/7 Title:


1 A8 10 GND 11 B8 14 B7 15 B6 16 B5 17 B4 18 B3 19 DIR 2 B2 20 B1 21 ~{OE}22 VCCB 23 VCCB 24 A1 3 A2 4 A3 5 A4 6 A5 7 A6 8 A7 9 SN74LVC8T245 U3 +3V3 GNDD VCCA

1 A8 10 GND 11 B8 14 B7 15 B6 16 B5 17 B4 18 B3 19 DIR 2 B2 20 B1 21 ~{OE}22 VCCB 23 VCCB 24 A1 3 A2 4 A3 5 A4 6 A5 7 A6 8 A7 9 SN74LVC8T245 U5 VCCA

1 A8 10 GND 11 B8 14 B7 15 B6 16 B5 17 B4 18 B3 19 DIR 2 B2 20 B1 21 ~{OE}22 VCCB 23 VCCB 24 A1 3 A2 4 A3 5 A4 6 A5 7 A6 8 A7 9 SN74LVC8T245 U9

1 A8 10 GND 11 B8 14 B7 15 B6 16 B5 17 B4 18 B3 19 DIR 2 B2 20 B1 21 ~{OE}22 VCCB 23 VCCB 24 A1 3 A2 4 A3 5 A4 6 A5 7 A6 8 A7 9 SN74LVC8T245 U14 VCCA

1 A8 10 GND 11 B8 14 B7 15 B6 16 B5 17 B4 18 B3 19 DIR 2 B2 20 B1 21 ~{OE}22 VCCB 23 VCCB 24 A1 3 A2 4 A3 5 A4 6 A5 7 A6 8 A7 9 SN74LVC8T245 U6 +3V3 GNDD

1 A8 10 GND 11 B8 14 B7 15 B6 16 B5 17 B4 18 B3 19 DIR 2 B2 20 B1 21 ~{OE}22 VCCB 23 VCCB 24 A1 3 A2 4 A3 5 A4 6 A5 7 A6 8 A7 9 SN74LVC8T245 U4 GNDD

1 A8 10 GND 11 B8 14 B7 15 B6 16 B5 17 B4 18 B3 19 DIR 2 B2 20 B1 21 ~{OE}22 VCCB 23 VCCB 24 A1 3 A2 4 A3 5 A4 6 A5 7 A6 8 A7 9 SN74LVC8T245 U7 GNDD

File: Shifters.kicad_sch Sheet: /Shifters/
Id: 6/7 Title:


File: Sound.kicad_sch Sheet: /Sound/
Id: 7/7 Title:

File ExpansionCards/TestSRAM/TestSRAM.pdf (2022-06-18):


SCL ~{IACKX} ~{RESET} MASTERCLK MPUCLK

4 SDA 5 SCL 6 WP 7 VCC

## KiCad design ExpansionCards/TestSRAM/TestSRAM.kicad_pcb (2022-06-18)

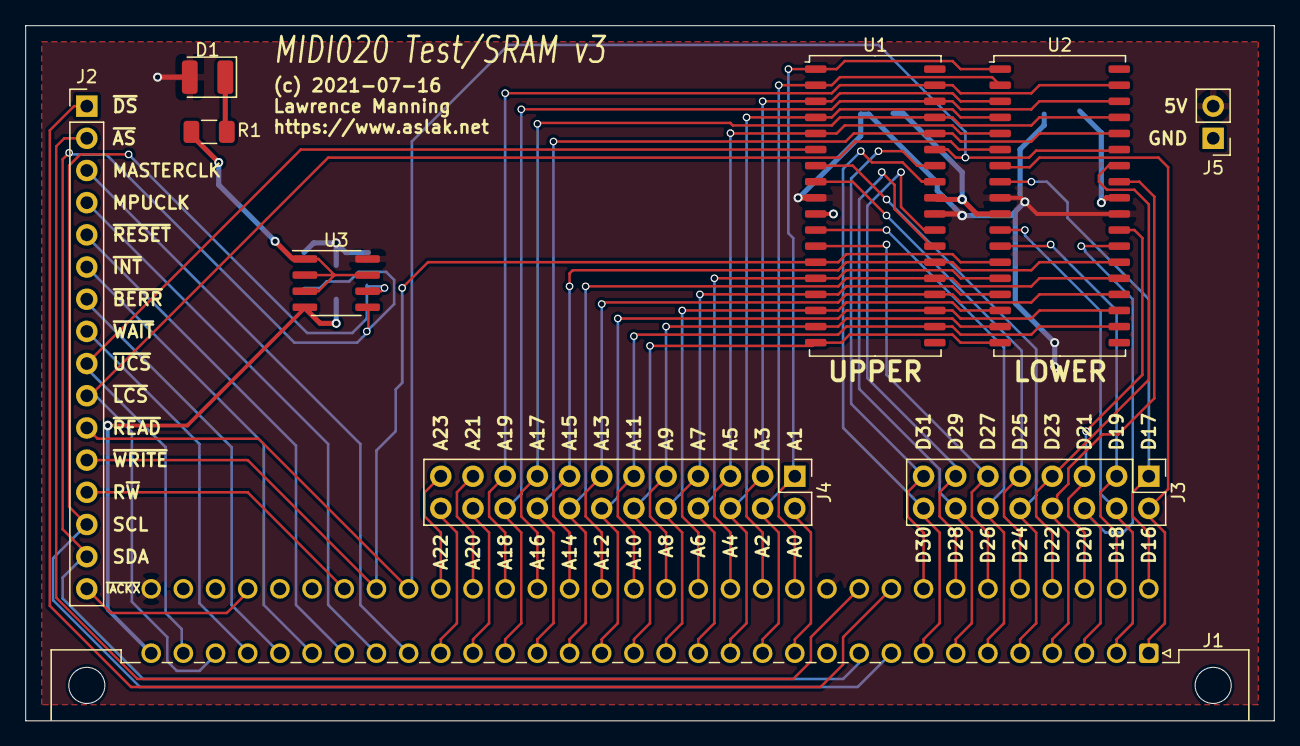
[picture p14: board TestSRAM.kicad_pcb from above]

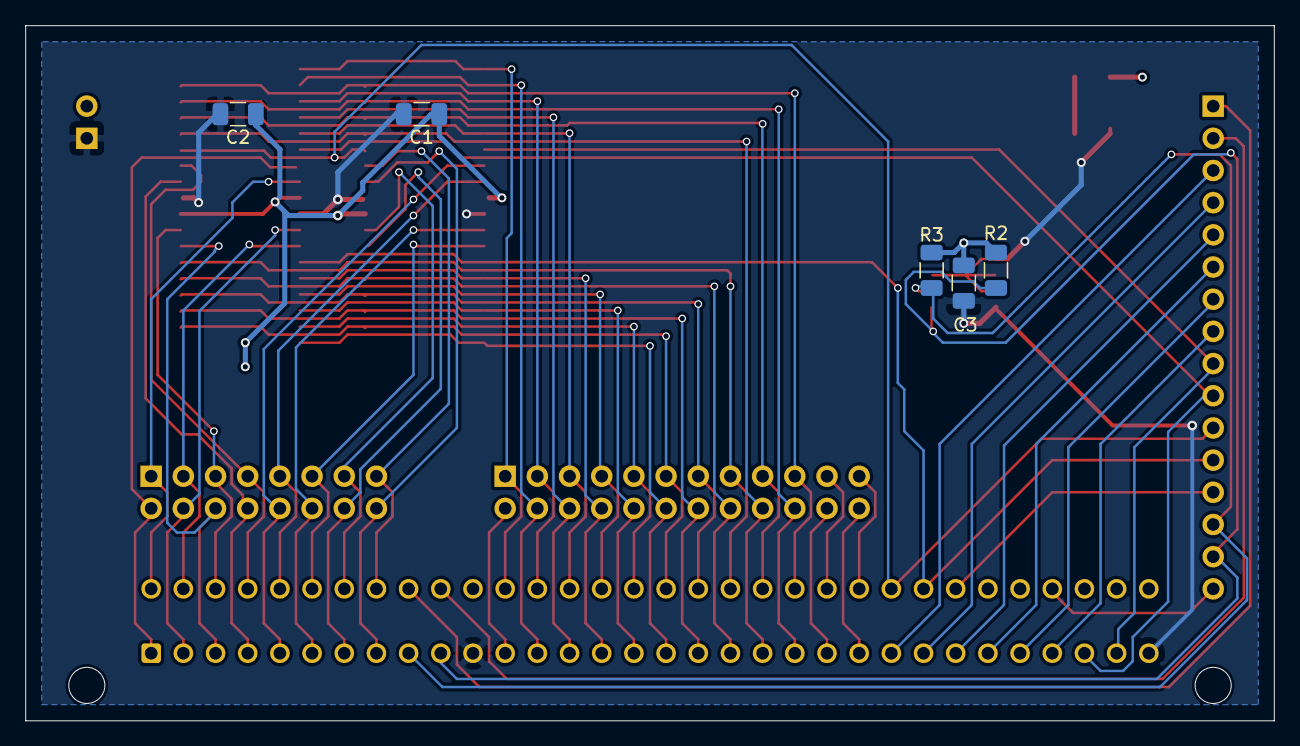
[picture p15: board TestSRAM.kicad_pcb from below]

Board: 2 copper layers, 98.6 x 54.9 mm, 15 parts (5 on the bottom side), 59 nets.

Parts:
C1, C2, C3: 0.1u; C_1206_3216Metric
D1: LED; LED_1210_3225Metric
J1: DIN_41612_3x32_MIDI020_CARD; DIN41612_C_2x32_Male_Horizontal_THT
J2: Conn_01x16; PinHeader_1x16_P2.54mm_Vertical
J3: Conn_02x08_Odd_Even; PinHeader_2x08_P2.54mm_Vertical
J4: Conn_02x12_Odd_Even; PinHeader_2x12_P2.54mm_Vertical
J5: Conn_01x02; PinHeader_1x02_P2.54mm_Vertical
R1: 1K; R_1206_3216Metric
R2, R3: 4.7K; R_1206_3216Metric
U1, U2: IS61C5128AL-10KLI; SOJ-36_10.16x23.49mm_P1.27mm
U3: AT24CS64-SSHM; SOIC-8_3.9x4.9mm_P1.27mm

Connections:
+5VD: C1.1, C2.1, C3.1, D1.2, J1.c11, J1.c32, J5.2, R2.1, R3.1, U1.9, U1.27, U2.9, U2.27, U3.8
/A0: J1.a12, J4.2
/A1: J1.c12, J4.1, U1.1, U2.1
/A2: J1.a13, J4.4, U1.2, U2.2
/A3: J1.c13, J4.3, U1.3, U2.3
/A4: J1.a14, J4.6, U1.4, U2.4
/A5: J1.c14, J4.5, U1.5, U2.5
/A6: J1.a15, J4.8, U1.14, U2.14
/A7: J1.c15, J4.7, U1.15, U2.15
/A8: J1.a16, J4.10, U1.16, U2.16
/A9: J1.c16, J4.9, U1.17, U2.17
/A10: J1.a17, J4.12, U1.18, U2.18
/A11: J1.c17, J4.11, U1.20, U2.20
/A12: J1.a18, J4.14, U1.21, U2.21
/A13: J1.c18, J4.13, U1.22, U2.22
/A14: J1.a19, J4.16, U1.23, U2.23
/A15: J1.c19, J4.15, U1.24, U2.24
/A16: J1.a20, J4.18, U1.32, U2.32
/A17: J1.c20, J4.17, U1.33, U2.33
/A18: J1.a21, J4.20, U1.34, U2.34
/A19: J1.c21, J4.19, U1.35, U2.35
/A20: J1.a22, J4.22
/A21: J1.c22, J4.21
/A22: J1.a23, J4.24
/A23: J1.c23, J4.23
/D16: J1.a1, J3.2, U2.7
/D17: J1.c1, J3.1, U2.8
/D18: J1.a2, J3.4, U2.11
/D19: J1.c2, J3.3, U2.12
/D20: J1.a3, J3.6, U2.25
/D21: J1.c3, J3.5, U2.26
/D22: J1.a4, J3.8, U2.29
/D23: J1.c4, J3.7, U2.30
/D24: J1.a5, J3.10, U1.7
/D25: J1.c5, J3.9, U1.8
/D26: J1.a6, J3.12, U1.11
/D27: J1.c6, J3.11, U1.12
/D28: J1.a7, J3.14, U1.25
/D29: J1.c7, J3.13, U1.26
/D30: J1.a8, J3.16, U1.29
/D31: J1.c8, J3.15, U1.30
GNDD: C1.2, C2.2, C3.2, J1.a11, J1.a32, J5.1, R1.1, U1.10, U1.28, U2.10, U2.28, U3.1, U3.2, U3.3, U3.4, U3.7
MASTERCLK: J1.a24, J2.3
MPUCLK: J1.a25, J2.4
unnamed: D1.1, R1.2
R~W: J1.c26, J2.13
SCL: J1.a9, J2.14, R3.2, U3.6
SDA: J1.a10, J2.15, R2.2, U3.5
~AS: J1.c10, J2.2
~BERR: J1.a28, J2.7
~DS: J1.c9, J2.1
~IACKX: J1.c29, J2.16
~INT: J1.a27, J2.6
~LCS: J1.a30, J2.10, U2.6
~READ: J1.c24, J2.11, U1.31, U2.31
~RESET: J1.a26, J2.5
~UCS: J1.a31, J2.9, U1.6
~WAIT: J1.a29, J2.8
~WRITE: J1.c25, J2.12, U1.13, U2.13

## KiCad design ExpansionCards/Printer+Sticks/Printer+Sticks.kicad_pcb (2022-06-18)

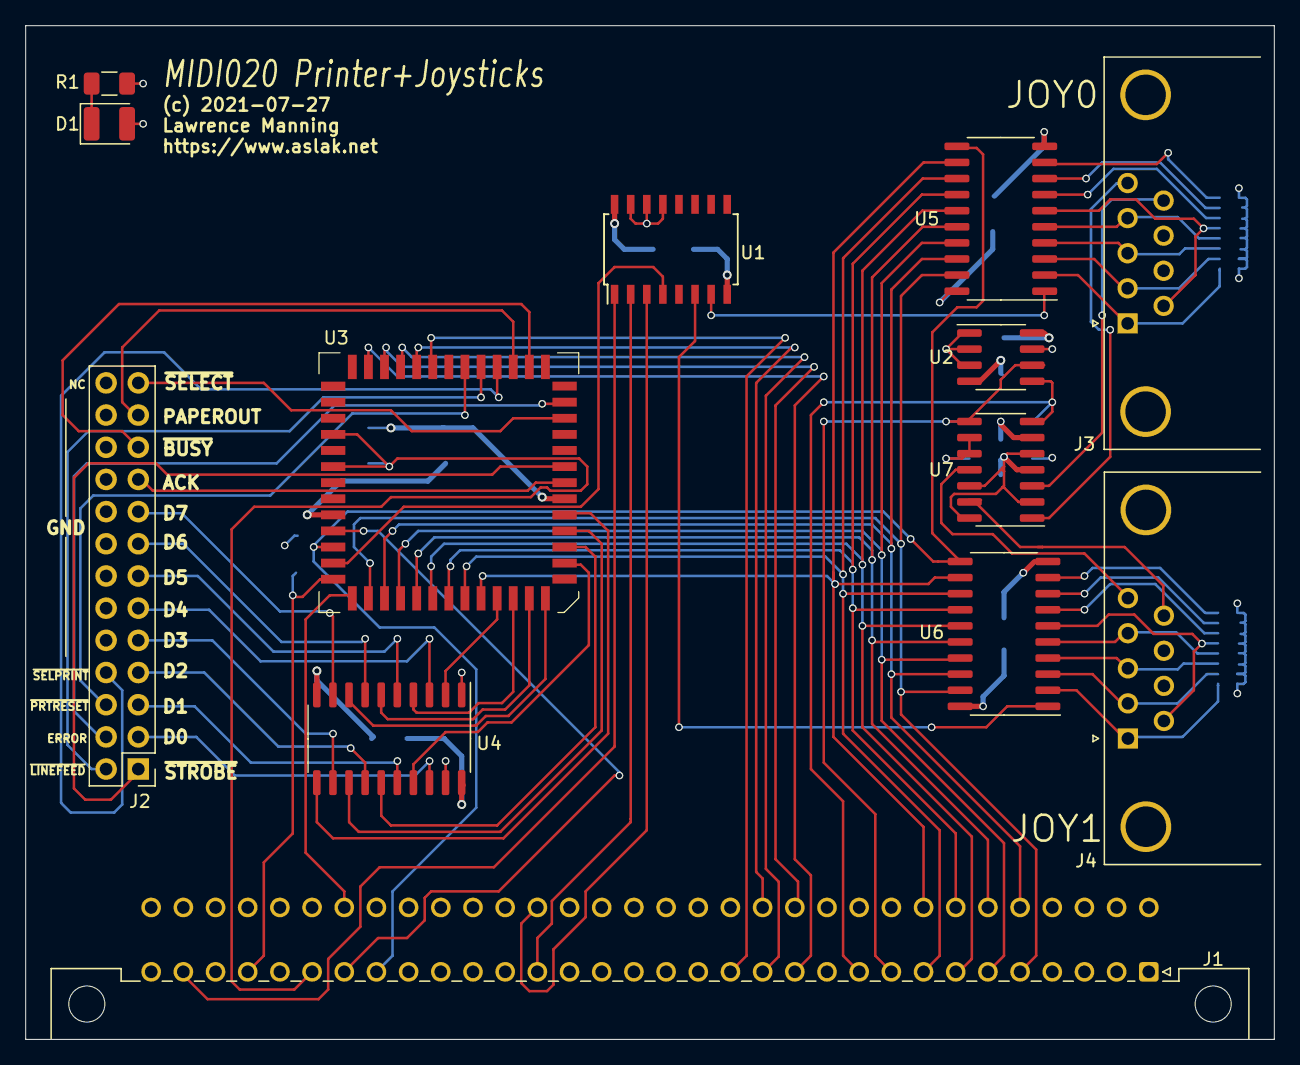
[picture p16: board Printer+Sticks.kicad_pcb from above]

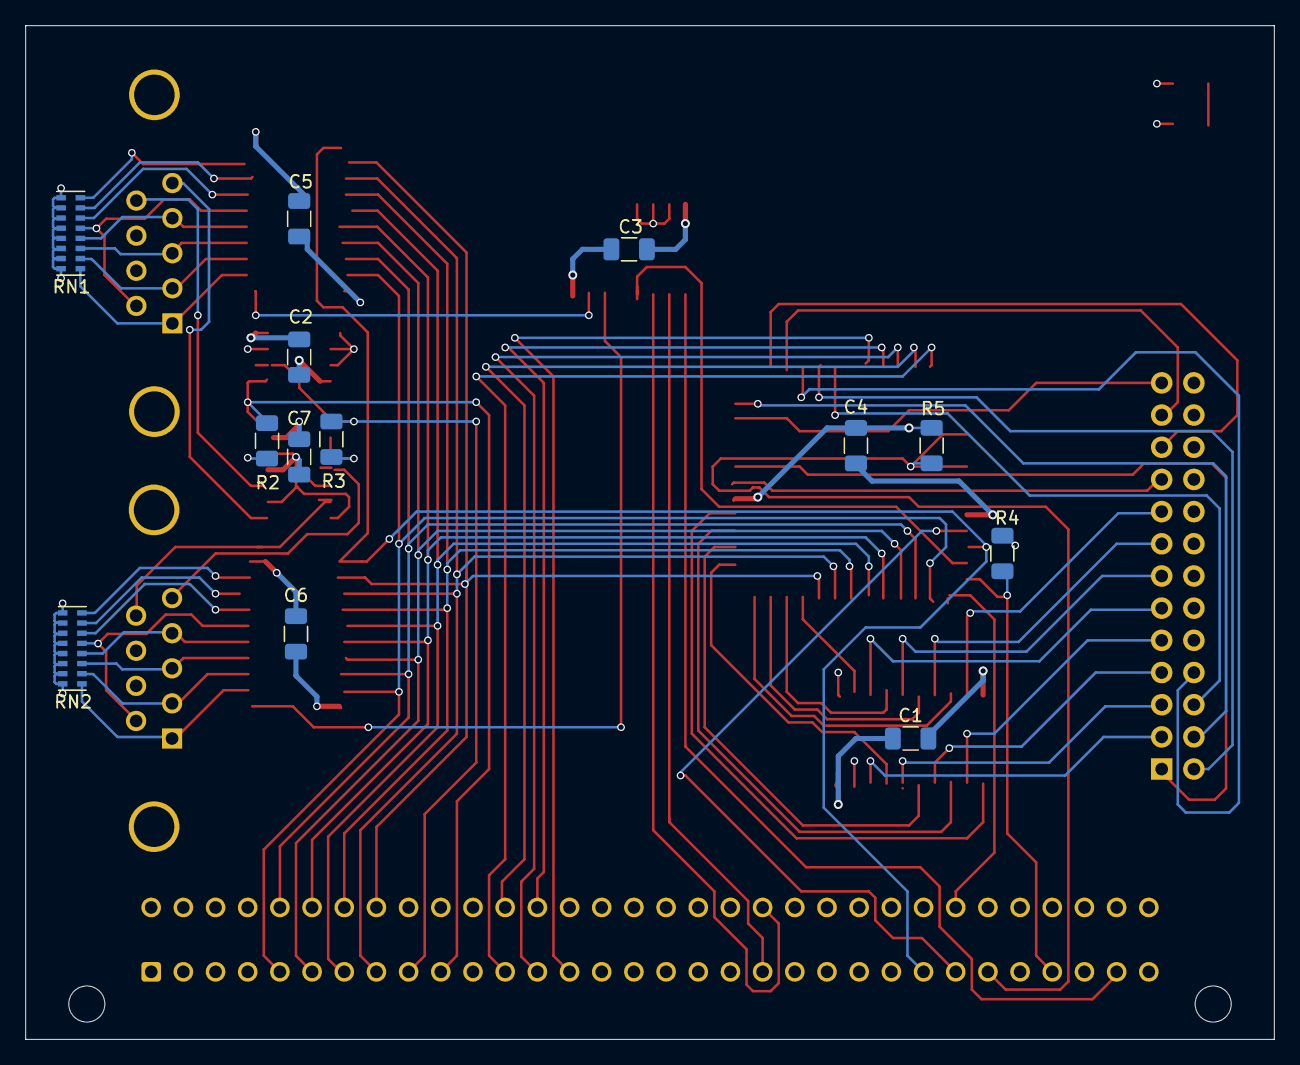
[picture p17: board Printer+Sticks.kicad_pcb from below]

Board: 4 copper layers, 98.6 x 80.0 mm, 26 parts (13 on the bottom side), 74 nets.

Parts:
C1, C2, C3, C4, C5, C6, C7: 0.1u; C_1206_3216Metric
D1: LED; LED_1210_3225Metric
J1: DIN_41612_3x32_MIDI020_CARD; DIN41612_C_2x32_Male_Horizontal_THT
J2: Conn_02x13_Odd_Even; PinHeader_2x13_P2.54mm_Vertical
J3, J4: DB9_Male_MountingHoles; DSUB-9_Male_Horizontal_P2.77x2.84mm_EdgePinOffset7.70mm_Hou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
R1: 1K; R_1206_3216Metric
R2, R3, R4, R5: 4.7K; R_1206_3216Metric
RN1, RN2: 10K; R_Cat16-8
U1: 74LS139; SOIC-16W_5.3x10.2mm_P1.27mm
U2: AT24CS64-SSHM; SOIC-8_3.9x4.9mm_P1.27mm
U3: MC68230; PLCC-52
U4: 74HC244; SO-20_5.3x12.6mm_P1.27mm
U5, U6: 74LS574; SO-20_5.3x12.6mm_P1.27mm
U7: MCP3428; SOIC-14_3.9x8.7mm_P1.27mm

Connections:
+5VD: C1.1, C2.1, C3.1, C4.1, C5.1, C6.1, C7.1, D1.2, J1.c11, J1.c32, J3.7, J4.7, R2.1, R3.1, R4.1, R5.1, RN1.9, RN1.10, RN1.11, RN1.12, RN1.13, RN1.14, RN1.15, RN1.16, RN2.9, RN2.10, RN2.11, RN2.12, RN2.13, RN2.14, RN2.15, RN2.16, U1.13, U1.14, U1.15, U1.16, U2.8, U3.13, U4.20, U5.20, U6.20, U7.6, U7.9, U7.10
/Printer/ACK: J2.19, U3.14
/Printer/ERROR: J2.4, U3.19
/Printer/PA0: U3.4, U4.2
/Printer/PA1: U3.5, U4.4
/Printer/PA2: U3.6, U4.6
/Printer/PA3: U3.7, U4.8
/Printer/PA4: U3.9, U4.17
/Printer/PA5: U3.10, U4.15
/Printer/PA6: U3.11, U4.13
/Printer/PA7: U3.12, U4.11
/Printer/PAPEROUT: J2.23, U3.23
/Printer/PRTD0: J2.3, U4.18
/Printer/PRTD1: J2.5, U4.16
/Printer/PRTD2: J2.7, U4.14
/Printer/PRTD3: J2.9, U4.12
/Printer/PRTD4: J2.11, U4.3
/Printer/PRTD5: J2.13, U4.5
/Printer/PRTD6: J2.15, U4.7
/Printer/PRTD7: J2.17, U4.9
/Printer/~BUSY: J2.21, U3.22
/Printer/~LINEFEED: J2.2, U3.25
/Printer/~PRTRESET: J2.6, U3.26
/Printer/~SELECTPRINTER: J2.8, U3.24
/Printer/~SELECT: J2.25, U3.18
/Printer/~STROBE: J2.1, U3.15
A0: J1.a12, U3.32
A1: J1.c12, U3.31
A2: J1.a13, U3.30
A3: J1.c13, U3.29
A4: J1.a14, U3.28
A16: J1.a20, U1.2
A17: J1.c20, U1.3
D24: J1.a5, U3.48, U5.19, U6.19
D25: J1.c5, U3.49, U5.18, U6.18
D26: J1.a6, U3.50, U5.17, U6.17
D27: J1.c6, U3.51, U5.16, U6.16
D28: J1.a7, U3.52, U5.15, U6.15
D29: J1.c7, U3.1, U5.14, U6.14
D30: J1.a8, U3.2, U5.13, U6.13
D31: J1.c8, U3.3, U5.12, U6.12
GNDD: C1.2, C2.2, C3.2, C4.2, C5.2, C6.2, C7.2, J1.a11, J1.a32, J2.10, J2.12, J2.14, J2.16, J2.18, J2.20, J2.22, J2.24, J3.0, J3.8, J4.0, J4.8, R1.1, U1.8, U2.1, U2.2, U2.3, U2.4, U2.7, U3.42, U4.1, U4.10, U4.19, U5.10, U6.10, U7.2, U7.4, U7.5, U7.12, U7.14
JOY0XPOT: J3.5, U7.1
JOY0YPOT: J3.9, U7.3
JOY1XPOT: J4.5, U7.11
JOY1YPOT: J4.9, U7.13
MPUCLK: J1.a25, U3.44, U5.11, U6.11
unnamed: D1.1, R1.2
unnamed: RN1.6, U5.7
unnamed: RN1.7, U5.8
unnamed: RN1.8, U5.9
unnamed: RN2.6, U6.7
unnamed: RN2.7, U6.8
unnamed: RN2.8, U6.9
R~W: J1.c26, U3.47
SCL: J1.a9, R3.2, U2.6, U7.8
SDA: J1.a10, R2.2, U2.5, U7.7
~INT: J1.a27, R5.2, U3.37, U3.39
~JOY0CS: U1.7, U5.1
~JOY0DOWN: J3.2, RN1.2, U5.3
~JOY0FIRE: J3.6, RN1.5, U5.6
~JOY0LEFT: J3.3, RN1.3, U5.4
~JOY0RIGHT: J3.4, RN1.4, U5.5
~JOY0UP: J3.1, RN1.1, U5.2
~JOY1CS: U1.6, U6.1
~JOY1DOWN: J4.2, RN2.2, U6.3
~JOY1FIRE: J4.6, RN2.5, U6.6
~JOY1LEFT: J4.3, RN2.3, U6.4
~JOY1RIGHT: J4.4, RN2.4, U6.5
~JOY1UP: J4.1, RN2.1, U6.2
~PITCS: U1.4, U3.45
~RESET: J1.a26, U3.43
~UCS: J1.a31, U1.1
~WAIT: J1.a29, R4.2, U3.46

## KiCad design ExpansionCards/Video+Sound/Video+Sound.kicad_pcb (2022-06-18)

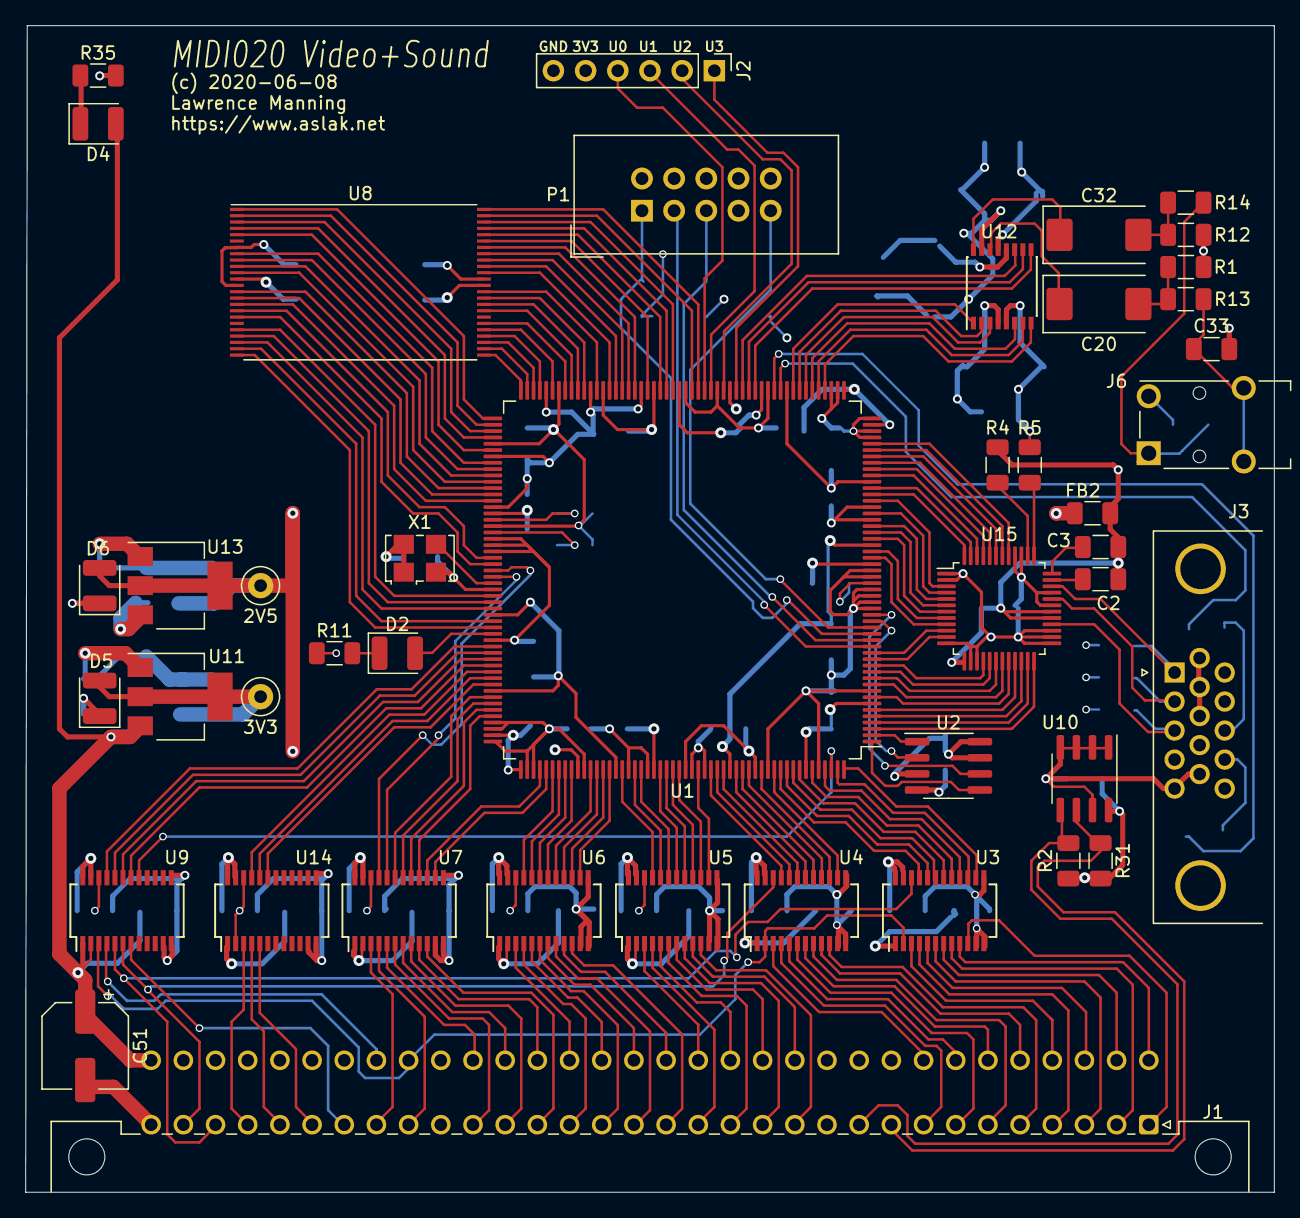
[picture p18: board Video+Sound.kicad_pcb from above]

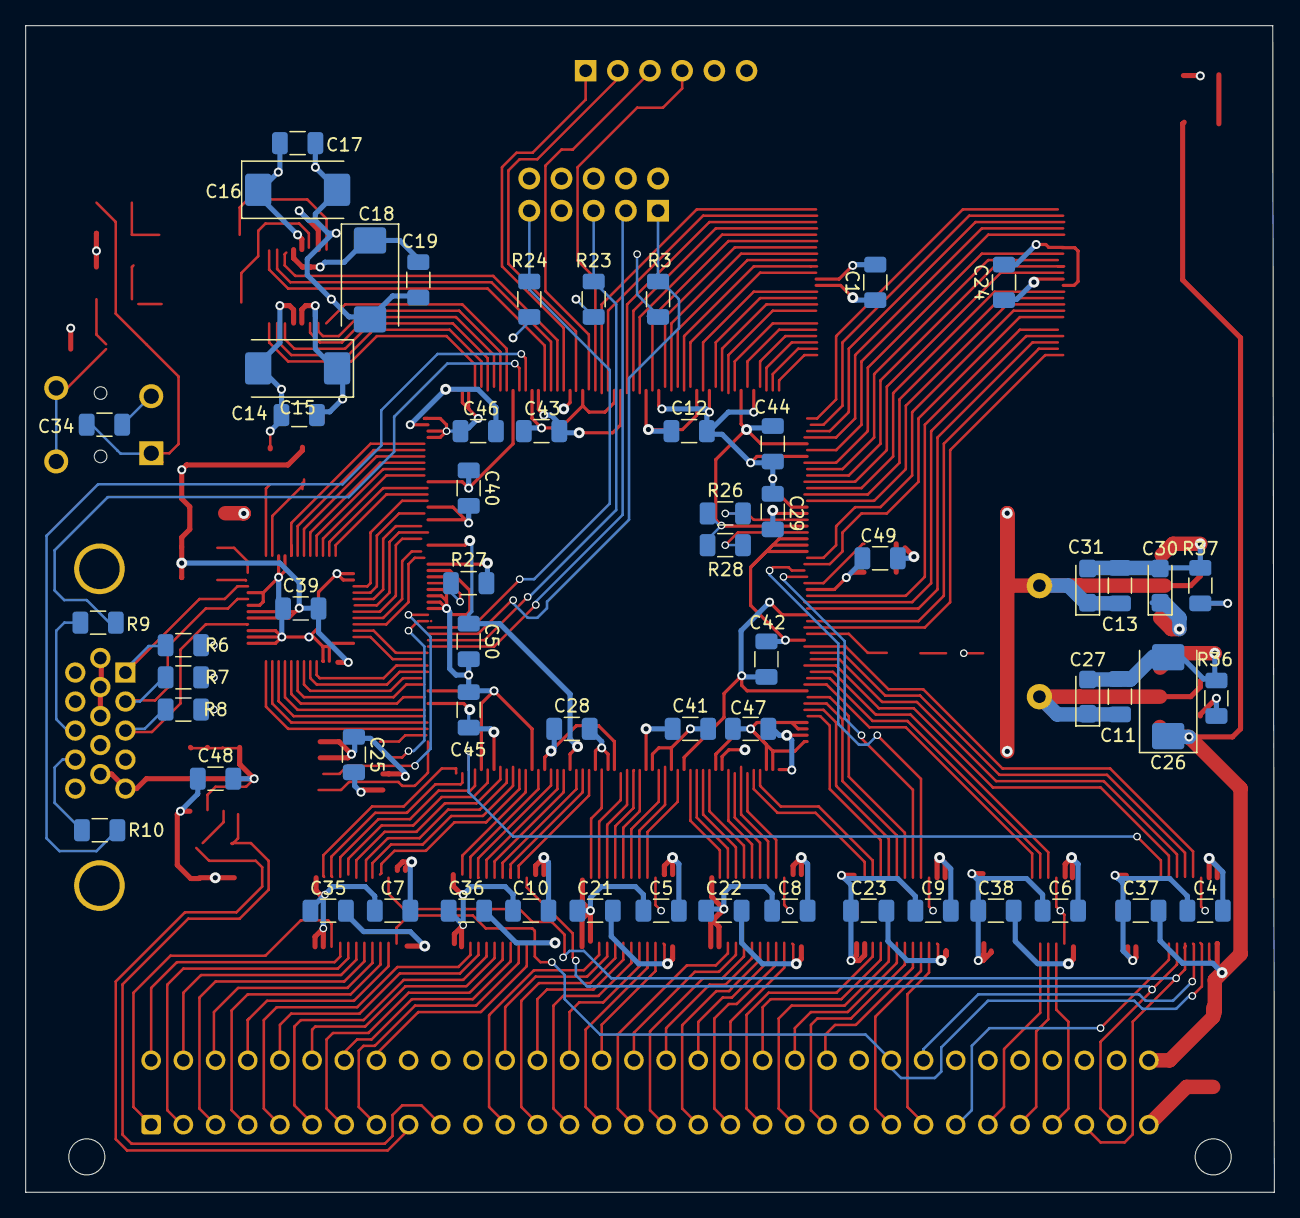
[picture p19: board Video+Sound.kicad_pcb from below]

Board: 4 copper layers, 98.6 x 92.1 mm, 102 parts (58 on the bottom side), 217 nets.

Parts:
C1, C2, C3, C4, C5, C6, C7, C8, C9, C10, C11, C12, C13, C14, C17, C19, C21, C22, C23, C24, C25, C28, C35, C36, C37, C38, C39, C41, C42, C43, C44, C45, C46, C47, C48, C49, C50: 0.1u; C_1206_3216Metric
C15, C16, C18, C20, C26, C32: 47u; CP_EIA-7343-15_Kemet-W
C27, C30, C31: 10u; CP_EIA-3216-10_Kemet-I
C29, C40: 1n; C_1206_3216Metric
C33, C34: 10n; C_1206_3216Metric
C51: 220u; CP_Elec_6.3x7.7
D2, D4, D5, D6: LED; LED_1210_3225Metric
FB2: Bead; L_1206_3216Metric
J1: DIN_41612_3x32_MIDI020_CARD; DIN41612_C_2x32_Male_Horizontal_THT
J2: Conn_01x06; PinHeader_1x06_P2.54mm_Vertical
J3: DB15HD_FEMALE_SVGA; DSUB-15-HD_Female_Horizontal_P2.29x1.98mm_EdgePinOffset3.03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
J6: STEREO_AUDIOJACK; Jack_3.5mm_Switronic_ST-005-G_horizontal
P1: CONN_02X05_JTAG; IDC-Header_2x05_P2.54mm_Vertical
R1, R12: 220K; R_1206_3216Metric
R2, R5, R31: 4.7K; R_1206_3216Metric
R3, R11, R23, R24, R35, R36, R37: 1K; R_1206_3216Metric
R4: 530; R_1206_3216Metric
R6, R7, R8: 75; R_1206_3216Metric
R9, R10: 47; R_1206_3216Metric
R13, R14: 100; R_1206_3216Metric
R26, R27, R28: 10K; R_1206_3216Metric
TP9: 3V3; TestPoint_Loop_D1.80mm_Drill1.0mm_Beaded
TP11: 2V5; TestPoint_Loop_D1.80mm_Drill1.0mm_Beaded
U1: EP2C8Q208I8N; PQFP-208_28x28mm_P0.5mm
U2: EPCQnA; SOIC-8_3.9x4.9mm_P1.27mm
U3, U4, U5, U6, U7, U9, U14: SN74LVC8T245; SSOP-24_3.9x8.7mm_P0.635mm
U8: IS61WV102416BLL-10TLI; TSOP-I-48_18.4x12mm_P0.5mm
U10: AT24CS64-SSHM; SOIC-8_3.9x4.9mm_P1.27mm
U11: AZ1117-3.3; SOT-223-3_TabPin2
U12: UDA1334ATS; SSOP-16_4.4x5.2mm_P0.65mm
U13: AZ1117-1.2; SOT-223-3_TabPin2
U15: ADV7123KSTZ140; LQFP-48_7x7mm_P0.5mm
X1: MASTEROSC; Oscillator_SMD_SeikoEpson_SG8002LB-4Pin_5.0x3.2mm

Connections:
+1V2: C13.1, C29.1, C31.1, C41.1, C43.1, C46.1, C47.1, C50.1, D6.2, TP11.1, U1.32, U1.51, U1.53, U1.66, U1.79, U1.120, U1.155, U1.157, U1.178, U1.190, U13.2
+3.3VDAC: C2.2, C3.2, C16.1, C17.1, C39.1, FB2.1, R5.1, U12.13, U15.13, U15.29, U15.30
+3V3: C1.1, C4.1, C5.1, C6.1, C7.1, C8.1, C9.1, C10.1, C11.1, C12.1, C14.1, C15.1, C24.1, C25.1, C27.1, C28.1, C30.1, C40.1, C42.1, C44.1, C45.1, C49.1, D5.2, FB2.2, J2.5, P1.4, R23.1, R24.1, R26.1, R27.1, R28.1, TP9.1, U1.7, U1.29, U1.42, U1.62, U1.71, U1.83, U1.91, U1.98, U1.109, U1.122, U1.136, U1.148, U1.166, U1.172, U1.183, U1.194, U1.202, U2.3, U2.7, U2.8, U3.23, U3.24, U4.23, U4.24, U5.23, U5.24, U6.23, U6.24, U7.23, U7.24, U8.12, U8.36, U9.23, U9.24, U11.2, U12.4, U13.3, U14.23, U14.24, X1.1, X1.4
+5VD: C21.1, C22.1, C23.1, C26.1, C35.1, C36.1, C37.1, C38.1, C48.1, C51.1, D4.2, J1.c11, J1.c32, R2.1, R31.1, U3.1, U4.1, U5.1, U5.2, U6.1, U6.2, U7.1, U7.2, U9.1, U9.2, U10.8, U11.3, U14.1
/FPGA/USER0: J2.4, U1.75
/FPGA/USER1: J2.3, U1.74
/FPGA/USER2: J2.2, U1.72
/FPGA/USER3: J2.1, U1.70
/Sound/VOUTL: C20.1, U12.14
/Sound/VOUTR: C32.1, U12.16
/Sound/VREF: C18.1, C19.1, U12.12
A0: J1.a12, U5.10
A1: J1.c12, U5.9
A2: J1.a13, U5.8
A3: J1.c13, U5.7
A4: J1.a14, U5.6
A5: J1.c14, U5.5
A6: J1.a15, U5.4
A7: J1.c15, U5.3
A8: J1.a16, U6.10
A9: J1.c16, U6.9
A10: J1.a17, U6.8
A11: J1.c17, U6.7
A12: J1.a18, U6.6
A13: J1.c18, U6.5
A14: J1.a19, U6.4
A15: J1.c19, U6.3
A16: J1.a20, U7.10
A17: J1.c20, U7.9
A18: J1.a21, U7.8
A19: J1.c21, U7.7
A20: J1.a22, U7.6
A21: J1.c22, U7.5
BLUE: J3.3, R8.1, U15.28
BLUE0: U1.13, U15.16
BLUE1: U1.12, U15.17
BLUE2: U1.11, U15.18
BLUE3: U1.10, U15.19
BLUE4: U1.8, U15.20
BLUE5: U1.6, U15.21
BLUE6: U1.5, U15.22
BLUE7: U1.4, U15.23
CFGASDI: U1.1, U2.5
CFGDATA: U1.20, U2.2
CFGDCLK: U1.21, U2.6
D16: J1.a1, U3.10
D17: J1.c1, U3.9
D18: J1.a2, U3.8
D19: J1.c2, U3.7
D20: J1.a3, U3.6
D21: J1.c3, U3.5
D22: J1.a4, U3.4
D23: J1.c4, U3.3
D24: J1.a5, U4.10
D25: J1.c5, U4.9
D26: J1.a6, U4.8
D27: J1.c6, U4.7
D28: J1.a7, U4.6
D29: J1.c7, U4.5
D30: J1.a8, U4.4
D31: J1.c8, U4.3
DACCLK: U1.3, U15.24
GNDA: C1.2, C4.2, C5.2, C6.2, C7.2, C8.2, C9.2, C10.2, C11.2, C12.2, C13.2, C14.2, C15.2, C16.2, C17.2, C18.2, C19.2, C21.2, C22.2, C23.2, C24.2, C25.2, C26.2, C27.2, C28.2, C29.2, C30.2, C31.2, C33.2, C34.2, C35.2, C36.2, C37.2, C38.2, C39.2, C40.2, C41.2, C42.2, C43.2, C44.2, C45.2, C46.2, C47.2, C48.2, C49.2, C50.2, C51.2, J1.a11, J1.a32, J2.6, J3.0, J3.5, J3.6, J3.7, J3.8, J3.10, J6.S, P1.2, P1.10, R1.2, R3.2, R4.2, R6.2, R7.2, R8.2, R11.2, R12.2, R35.2, R36.2, R37.2, U1.9, U1.22, U1.23, U1.24, U1.25, U1.27, U1.28, U1.36, U1.38, U1.49, U1.50, U1.52, U1.54, U1.55, U1.65, U1.73, U1.78, U1.85, U1.93, U1.100, U1.111, U1.119, U1.124, U1.125, U1.126, U1.132, U1.140, U1.153, U1.154, U1.156, U1.158, U1.159, U1.167, U1.174, U1.177, U1.184, U1.186, U1.196, U1.204, U2.4, U3.11, U3.12, U3.13, U4.11, U4.12, U4.13, U5.11, U5.12, U5.13, U5.22, U6.11, U6.12, U6.13, U6.22, U7.11, U7.12, U7.13, U7.22, U8.7, U8.13, U8.37, U9.11, U9.12, U9.13, U9.22, U10.1, U10.2, U10.3, U10.4, U10.7, U11.1, U12.5, U12.15, U13.1, U14.2, U14.11, U14.12, U14.13, U14.22, U15.1, U15.2, U15.12, U15.14, U15.15, U15.25, U15.26, U15.27, U15.31, U15.33, U15.39, U15.40, X1.2
GREEN: J3.2, R7.1, U15.32
GREEN0: U1.39, U15.3
GREEN1: U1.37, U15.4
GREEN2: U1.35, U15.5
GREEN3: U1.34, U15.6
GREEN4: U1.33, U15.7
GREEN5: U1.31, U15.8
GREEN6: U1.30, U15.9
GREEN7: U1.15, U15.10
HSYNC: R9.1, U1.63
I2SBCLK: U1.61, U12.1
I2SDATAI: U1.59, U12.3
I2SDEEMCLKOUT: U1.67, U12.9
I2SMUTE: U1.56, U12.8
I2SPLL0: U1.68, U12.10
I2SSFOR0: U1.69, U12.11
I2SSFOR1: U1.57, U12.7
I2SSYSCLKPLL1: U1.58, U12.6
I2SWS: U1.60, U12.2
LA0: U1.185, U5.14
LA1: U1.182, U5.15
LA2: U1.181, U5.16
LA3: U1.180, U5.17
LA4: U1.179, U5.18
LA5: U1.176, U5.19
LA6: U1.175, U5.20
LA7: U1.173, U5.21
LA8: U1.171, U6.14
LA9: U1.170, U6.15
LA10: U1.169, U6.16
LA11: U1.168, U6.17
LA12: U1.165, U6.18
LA13: U1.164, U6.19
LA14: U1.163, U6.20
LA15: U1.162, U6.21
LA16: U1.161, U7.14
LA17: U1.160, U7.15
LA18: U1.152, U7.16
LA19: U1.151, U7.17
LA20: U1.150, U7.18
LA21: U1.149, U7.19
LD16: U1.208, U3.14
LD17: U1.207, U3.15
LD18: U1.205, U3.16
LD19: U1.203, U3.17
LD20: U1.201, U3.18
LD21: U1.200, U3.19
LD22: U1.199, U3.20
LD23: U1.198, U3.21
LD24: U1.197, U4.14
LD25: U1.195, U4.15
LD26: U1.193, U4.16
LD27: U1.192, U4.17
LD28: U1.191, U4.18
LD29: U1.189, U4.19
LD30: U1.188, U4.20
LD31: U1.187, U4.21
LMASTERCLK: U1.130, U7.20
LMPUCLK: U1.129, U7.21
MASTERCLK: J1.a24, U7.4
MPUCLK: J1.a25, U7.3
unnamed: C2.1, U15.35
unnamed: C3.1, U15.36
unnamed: C20.2, R1.1, R13.1
unnamed: C32.2, R12.1, R14.1
unnamed: C33.1, J6.T, R13.2
unnamed: C34.1, J6.R, R14.2
unnamed: D2.1, R11.1
unnamed: D4.1, R35.1
unnamed: D5.1, R36.1
unnamed: D6.1, R37.1
unnamed: J3.13, R9.2
unnamed: J3.14, R10.2
unnamed: R4.1, U15.37
unnamed: R5.2, U15.38
unnamed: R26.2, U1.121
unnamed: R27.2, U1.26
unnamed: R28.2, U1.123
RED: J3.1, R6.1, U15.34
RED0: U1.48, U15.41
RED1: U1.47, U15.42
RED2: U1.46, U15.43
RED3: U1.45, U15.44
RED4: U1.44, U15.45
RED5: U1.43, U15.46
RED6: U1.41, U15.47
RED7: U1.40, U15.48
SCL: J1.a9, R31.2, U10.6
SDA: J1.a10, R2.2, U10.5
TCK: P1.1, R3.1, U1.18
TDI: P1.9, R24.2, U1.19
TDO: P1.3, U1.16
TMS: P1.5, R23.2, U1.17
USERLED: D2.2, U1.139
VA0: U1.110, U8.5
VA1: U1.108, U8.4
VA2: U1.107, U8.3
VA3: U1.106, U8.2
VA4: U1.105, U8.1
VA5: U1.76, U8.48
VA6: U1.77, U8.47
VA7: U1.80, U8.46
VA8: U1.81, U8.45
VA9: U1.97, U8.30
VA10: U1.99, U8.29
VA11: U1.101, U8.28
VA12: U1.102, U8.27
VA13: U1.103, U8.26
VA14: U1.104, U8.25
VA15: U1.138, U8.24
VA16: U1.137, U8.23
VA17: U1.135, U8.22
VA18: U1.134, U8.21
VA19: U1.133, U8.20
VD0: U1.112, U8.8
VD1: U1.113, U8.9
VD2: U1.114, U8.10
VD3: U1.115, U8.11
VD4: U1.116, U8.14
VD5: U1.117, U8.15
VD6: U1.118, U8.16
VD7: U1.127, U8.17
VD8: U1.96, U8.32
VD9: U1.95, U8.33
VD10: U1.94, U8.34
VD11: U1.92, U8.35
VD12: U1.90, U8.38
VD13: U1.89, U8.39
VD14: U1.88, U8.40
VD15: U1.87, U8.41
VIDEOCLK: U1.131, X1.3
VSYNC: R10.1, U1.64
~BERR: J1.a28, U14.4
~CFGCS: U1.2, U2.1
~INT: J1.a27, U14.5
~LBERR: U1.146, U14.20
~LCS: J1.a30, U3.22, U9.5
~LINT: U1.147, U14.19
~LLCS: U1.143, U9.19
~LREAD: U1.141, U9.21
~LRESET: U1.206, U9.17
~LUCS: U1.144, U9.18
~LWAIT: U1.145, U14.21
~LWRITE: U1.142, U9.20
~READ: J1.c24, U3.2, U4.2, U9.3
~RESET: J1.a26, U9.7
~UCS: J1.a31, U4.22, U9.6
~VGABLANK: U1.14, U15.11
~VLCS: U1.86, U8.42
~VREAD: U1.82, U8.44
~VUCS: U1.84, U8.43
~VWRITE: U1.128, U8.18
~WAIT: J1.a29, U14.3
~WRITE: J1.c25, U9.4

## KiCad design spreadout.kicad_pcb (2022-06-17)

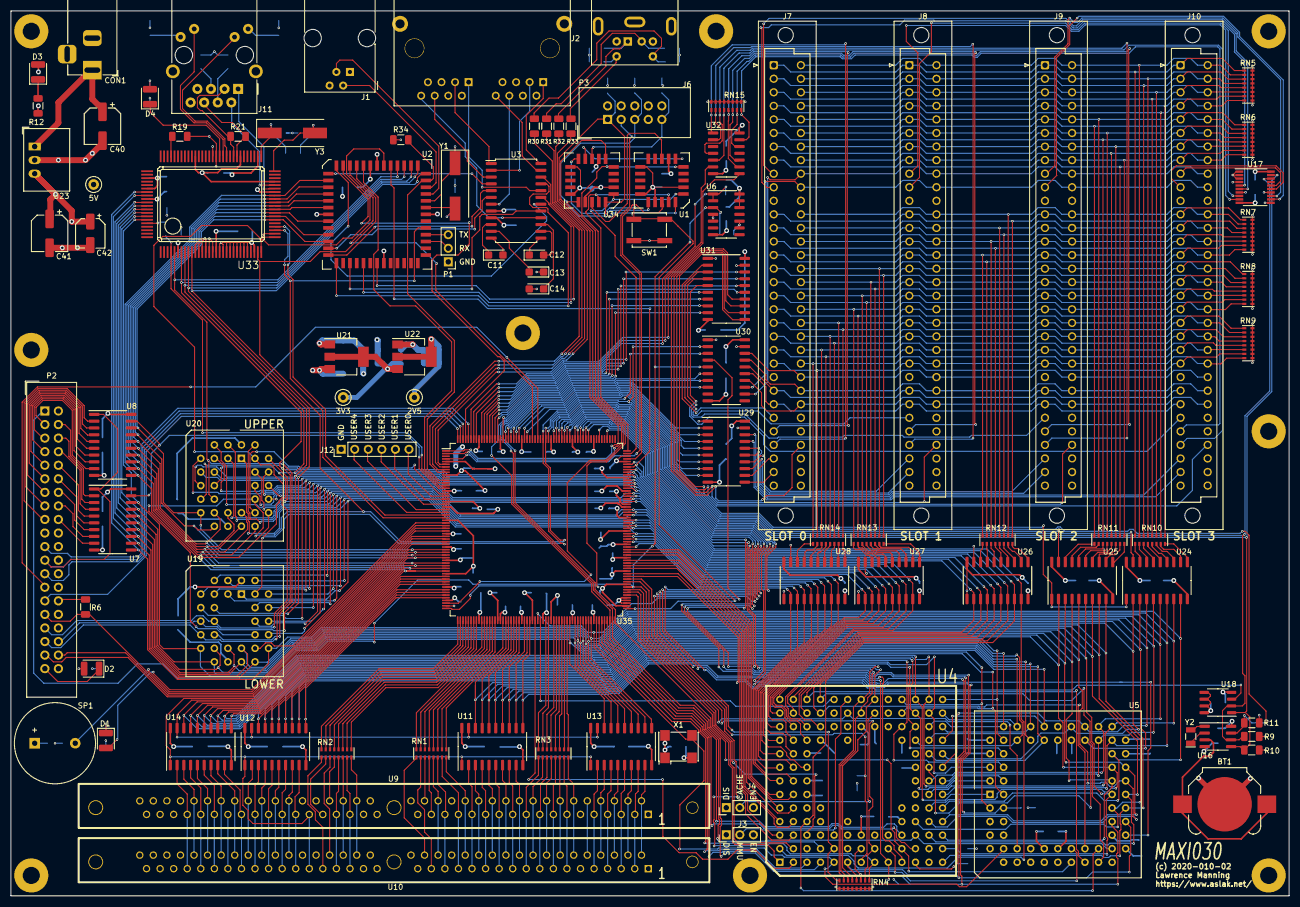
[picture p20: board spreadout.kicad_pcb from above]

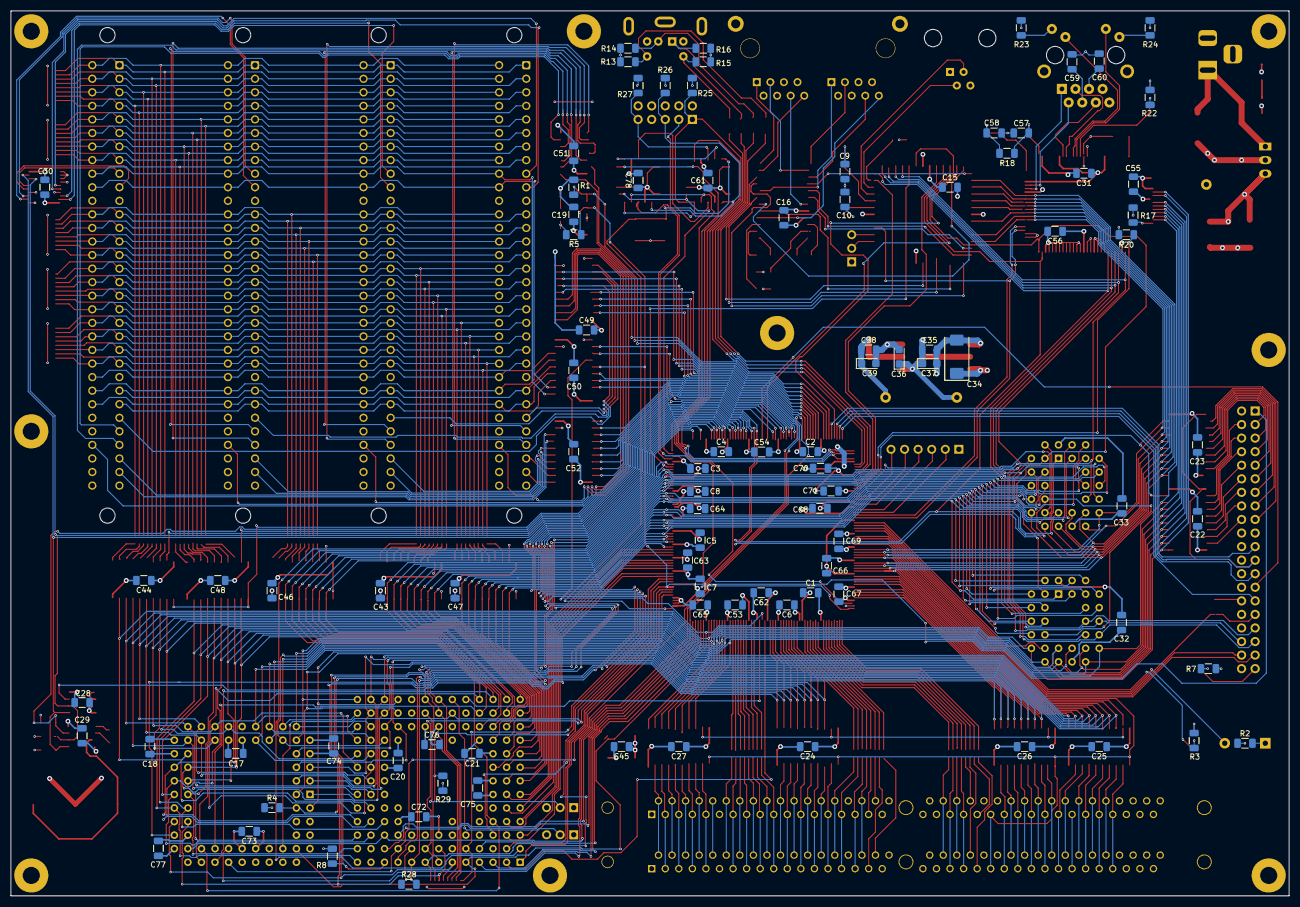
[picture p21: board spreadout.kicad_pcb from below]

Board: 4 copper layers, 239.4 x 165.7 mm, 199 parts (93 on the bottom side), 441 nets.

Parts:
BT1: Battery_Cell; BatteryHolder_Keystone_3000_1x12mm
C1, C2, C3, C4, C5, C6, C7, C8, C15, C16, C17, C18, C19, C20, C21, C22, C23, C24, C25, C26, C27, C28, C29, C30, C31, C32, C33, C35, C38, C43, C44, C45, C46, C47, C48, C49, C50, C51, C52, C53, C54, C55, C56, C61, C62, C63, C64, C65, C66, C67, C68, C69, C70, C71, C72, C73, C74, C75, C76, C77, C78: 0.1u; C_1206_3216Metric
C9, C10, C57, C58: 22p; C_1206_3216Metric
C11, C12, C13, C14: 1.0u; CP_EIA-3216-18_Kemet-A
C34: 47u; CP_EIA-7343-15_Kemet-W
C36, C37, C39: 10u; CP_EIA-3216-10_Kemet-I
C40: 470u; CP_Elec_6.3x7.7
C41: 220u; CP_Elec_6.3x7.7
C42: 10u; CP_Elec_5x5.7
C59, C60: 10n; C_1206_3216Metric
CON1: POWERLJACK; BarrelJack_Horizontal
D1: CORELED; LED_1210_3225Metric
D2: IDELED; LED_1210_3225Metric
D3: POWERLED; LED_1210_3225Metric
D4: LED; LED_1210_3225Metric
H1, H2, H3, H4, H5, H6, H7, H8, H9: MountingHole_Pad; MountingHole_3.2mm_M3_Pad
J1: RJ10_KEYBOARD; RJ10
J2: DUALRJ45_RS232; DUALRJ45
J3, J4: Conn_01x03; PinHeader_1x03_P2.54mm_Vertical
J6: Mini-DIN-6; Connector_Mini-DIN_Female_6Pin_2rows
J7, J8, J9, J10: DIN_41612_3x32_MIDI020_EXP; DIN41612_C_2x32_Female_Vertical_THT
J11: RJ45_Amphenol_RJMG1BD3B8K1ANR
J12: Conn_01x06; PinHeader_1x06_P2.54mm_Vertical
P1: TTL_SERIAL; PinHeader_1x03_P2.54mm_Vertical
P2: CONN_02X20_IDE; IDC-Header_2x20_P2.54mm_Vertical
P3: JTAG; IDC-Header_2x05_P2.54mm_Vertical
R1, R4, R5, R6, R8, R9, R10, R11, R13, R14, R15, R16, R28, R29, R34: 4.7K; R_1206_3216Metric
R2, R3, R7, R12, R20, R22, R23, R24, R25, R26, R27: 1K; R_1206_3216Metric
R17: 27K; R_1206_3216Metric
R18: 1M; R_1206_3216Metric
R19: 10K; R_1206_3216Metric
R21: 200; R_1206_3216Metric
R30, R31, R32, R33: 120; R_1206_3216Metric
RN1, RN2, RN3, RN10, RN11, RN12, RN13, RN14: 33; R_Cat16-8
RN4, RN15: 4.7K; R_Cat16-8
RN5, RN6, RN7, RN8, RN9: 10K; R_Cat16-8
SP1: BUZZER; Buzzer_15x7.5RM7.6
SW1: RESETBUTTON; SW_Push_1P1T_NO_CK_KSC6xxJ
TP1: 3V3; TestPoint_Loop_D1.80mm_Drill1.0mm_Beaded
TP2: 2V5; TestPoint_Loop_D1.80mm_Drill1.0mm_Beaded
TP3: 5V; TestPoint_Loop_D1.80mm_Drill1.0mm_Beaded
U1, U34: EPC2; PLCC-20
U2: SC26C94; PLCC-52
U3: MAX238; SOIC-24W_7.5x15.4mm_P1.27mm
U4: MC68030RC; PGA128
U5: 68882; PLCC-68_THT-Socket
U6: 74LS03; SOIC-14_3.9x8.7mm_P1.27mm
U7, U8, U24, U25, U26, U27, U28, U29, U30, U31: 74HCT245; SO-20_5.3x12.6mm_P1.27mm
U9, U10: SIM72Pin; SIMM72Pins
U11, U12, U13, U14: 74HC245; SO-20_5.3x12.6mm_P1.27mm
U16: LM75A; SO-8_3.9x4.9mm_P1.27mm
U17: PCA9544APW; TSSOP-20_4.4x6.5mm_P0.65mm
U18: DS1307Z+; SOIC-8_3.9x4.9mm_P1.27mm
U19, U20: SST39SF040-PC32; PLCC-32_THT-Socket
U21: AZ1117-3.3; SOT-223-3_TabPin2
U22: AZ1117-2.5; SOT-223-3_TabPin2
U23: SR05S05; Converter_DCDC_RECOM_R-78E-0.5_THT
U32: 74LS21; SOIC-14_3.9x8.7mm_P1.27mm
U33: RTL8019AS
U35: EPF10K130EQC240; PQFP-240_32.1x32.1mm_P0.5mm
X1: MPUOSC; Oscillator_SMD_SeikoEpson_SG8002CA-4Pin_7.0x5.0mm
Y1: 7.3728M; Crystal_SMD_HC49-SD
Y2: 32.768; Crystal_SMD_EuroQuartz_EQ161-2Pin_3.2x1.5mm
Y3: 20M; Crystal_SMD_HC49-SD

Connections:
+2V5: C1.1, C3.1, C5.1, C7.1, C38.1, C39.1, C53.1, C62.1, C64.1, C66.1, C68.1, C70.1, TP2.1, U22.2, U35.5, U35.20, U35.27, U35.47, U35.76, U35.89, U35.96, U35.122, U35.130, U35.150, U35.159, U35.170
+3V3: C2.1, C4.1, C6.1, C8.1, C35.1, C36.1, C37.1, C54.1, C61.1, C63.1, C65.1, C67.1, C69.1, C71.1, C78.1, P3.4, R26.1, R27.1, TP1.1, U1.5, U1.14, U1.18, U1.20, U21.2, U22.3, U34.5, U34.14, U34.18, U34.20, U35.16, U35.37, U35.57, U35.59, U35.77, U35.112, U35.140, U35.160, U35.189, U35.205, U35.224
+5VD: C13.1, C15.1, C16.1, C17.1, C18.1, C19.1, C20.1, C21.1, C22.1, C23.1, C24.1, C25.1, C26.1, C27.1, C28.1, C29.1, C30.1, C31.1, C32.1, C33.1, C34.1, C41.1, C42.1, C43.1, C44.1, C45.1, C46.1, C47.1, C48.1, C49.1, C50.1, C51.1, C52.1, C55.1, C56.1, C72.1, C73.1, C74.1, C75.1, C76.1, C77.1, D3.2, J1.1, J3.1, J4.1, J6.4, J7.c11, J7.c32, J8.c11, J8.c32, J9.c11, J9.c32, J10.c11, J10.c32, P2.20, R1.1, R4.1, R5.2, R7.1, R8.1, R9.1, R10.1, R11.1, R13.2, R14.2, R15.2, R16.2, R22.1, R23.2, R24.2, R28.1, R29.1, R34.2, RN4.9, RN4.10, RN4.11, RN4.12, RN4.13, RN4.14, RN4.15, RN4.16, RN5.9, RN5.10, RN5.11, RN5.12, RN5.13, RN5.14, RN5.15, RN5.16, RN6.9, RN6.10, RN6.11, RN6.12, RN6.13, RN6.14, RN6.15, RN6.16, RN7.9, RN7.10, RN7.11, RN7.12, RN7.13, RN7.14, RN7.15, RN7.16, RN8.9, RN8.10, RN8.11, RN8.12, RN8.13, RN8.14, RN8.15, RN8.16, RN9.9, RN9.10, RN9.11, RN9.12, RN9.13, RN9.14, RN9.15, RN9.16, RN15.9, RN15.10, RN15.11, RN15.12, RN15.13, RN15.14, RN15.15, RN15.16, TP3.1, U2.2, U3.9, U4.C6, U4.D4, U4.D10, U4.F2, U4.F11, U4.H3, U4.H11, U4.K4, U4.K10, U4.L6, U5.10, U5.16, U5.17, U5.18, U5.26, U5.27, U5.43, U5.52, U5.53, U5.61, U6.4, U6.5, U6.9, U6.10, U6.12, U6.13, U6.14, U7.20, U8.20, U9.10, U9.30, U9.59, U10.10, U10.30, U10.59, U11.20, U12.20, U13.20, U14.20, U16.5, U16.6, U16.7, U16.8, U17.4, U17.7, U17.11, U17.14, U17.20, U18.8, U19.32, U20.32, U21.3, U23.3, U24.20, U25.20, U26.1, U26.20, U27.1, U27.20, U28.1, U28.20, U29.1, U29.20, U30.1, U30.20, U31.1, U31.20, U32.14, U33.6, U33.15, U33.16, U33.17, U33.31, U33.32, U33.47, U33.57, U33.65, U33.70, U33.89, X1.1, X1.4
/FPGA/USER0: J12.6, U35.18
/FPGA/USER1: J12.5, U35.19
/FPGA/USER2: J12.4, U35.21
/FPGA/USER3: J12.3, U35.23
/FPGA/USER4: J12.2, U35.24
/IDE/IDED0: P2.4, U7.2
/IDE/IDED1: P2.6, U7.3
/IDE/IDED2: P2.8, U7.4
/IDE/IDED3: P2.10, U7.5
/IDE/IDED4: P2.12, U7.6
/IDE/IDED5: P2.14, U7.7
/IDE/IDED6: P2.16, U7.8
/IDE/IDED7: P2.18, U7.9
/IDE/IDED8: P2.17, U8.2
/IDE/IDED9: P2.15, U8.3
/IDE/IDED10: P2.13, U8.4
/IDE/IDED11: P2.11, U8.5
/IDE/IDED12: P2.9, U8.6
/IDE/IDED13: P2.7, U8.7
/IDE/IDED14: P2.5, U8.8
/IDE/IDED15: P2.3, U8.9
/SIMM/SD0: U9.2, U10.2, U13.9
/SIMM/SD1: U9.4, U10.4, U13.7
/SIMM/SD2: U9.6, U10.6, U13.5
/SIMM/SD3: U9.8, U10.8, U13.3
/SIMM/SD4: U9.20, U10.20, U11.9
/SIMM/SD5: U9.22, U10.22, U11.7
/SIMM/SD6: U9.24, U10.24, U11.5
/SIMM/SD7: U9.26, U10.26, U11.3
/SIMM/SD8: U9.49, U10.49, U12.9
/SIMM/SD9: U9.51, U10.51, U12.7
/SIMM/SD10: U9.53, U10.53, U12.5
/SIMM/SD11: U9.55, U10.55, U12.3
/SIMM/SD12: U9.57, U10.57, U14.9
/SIMM/SD13: U9.61, U10.61, U14.6
/SIMM/SD14: U9.63, U10.63, U14.4
/SIMM/SD15: U9.65, U10.65, U14.2
/SIMM/SD16: U9.3, U10.3, U13.8
/SIMM/SD17: U9.5, U10.5, U13.6
/SIMM/SD18: U9.7, U10.7, U13.4
/SIMM/SD19: U9.9, U10.9, U13.2
/SIMM/SD20: U9.21, U10.21, U11.8
/SIMM/SD21: U9.23, U10.23, U11.6
/SIMM/SD22: U9.25, U10.25, U11.4
/SIMM/SD23: U9.27, U10.27, U11.2
/SIMM/SD24: U9.50, U10.50, U12.8
/SIMM/SD25: U9.52, U10.52, U12.6
/SIMM/SD26: U9.54, U10.54, U12.4
/SIMM/SD27: U9.56, U10.56, U12.2
/SIMM/SD28: U9.58, U10.58, U14.8
/SIMM/SD29: U9.60, U10.60, U14.7
/SIMM/SD30: U9.62, U10.62, U14.5
/SIMM/SD31: U9.64, U10.64, U14.3
A0: U2.51, U4.A2, U26.9, U35.174
A1: U2.50, U4.C4, U5.25, U19.12, U20.12, U26.8, U33.5, U35.173
A2: P2.35, U2.49, U4.D13, U5.24, U19.11, U20.11, U26.7, U33.7, U35.172
A3: P2.33, U2.48, U4.D12, U5.23, U19.10, U20.10, U26.6, U33.8, U35.171
A4: P2.36, U2.47, U4.C13, U5.22, U19.9, U20.9, U26.5, U33.9, U35.169
A5: U2.46, U4.C12, U19.8, U20.8, U26.4, U33.10, U35.168
A6: U4.D11, U19.7, U20.7, U26.3, U35.167
A7: U4.B13, U19.6, U20.6, U26.2, U35.166
A8: U4.B12, U19.5, U20.5, U27.9, U35.164
A9: U4.C11, U19.27, U20.27, U27.8, U35.163
A10: U4.A13, U19.26, U20.26, U27.7, U35.162
A11: U4.C10, U19.23, U20.23, U27.6, U35.161
A12: U4.B11, U19.25, U20.25, U27.5, U35.158
A13: U4.A12, U19.4, U20.4, U27.4, U35.157
A14: U4.B10, U19.28, U20.28, U27.3, U35.156
A15: U4.A11, U19.29, U20.29, U27.2, U35.154
A16: U4.B9, U19.3, U20.3, U28.9, U35.153
A17: U4.A10, U19.2, U20.2, U28.8, U35.152
A18: U4.C8, U19.30, U20.30, U28.7, U35.151
A19: U4.A9, U19.1, U20.1, U28.6, U35.149
A20: U4.B8, U28.5, U35.148
A21: U4.A8, U28.4, U35.147
A22: U4.B7, U28.3, U35.146
A23: U4.A7, U28.2, U35.144
A24: U4.A6, U35.143
A25: U4.B6, U35.142
A26: U4.A5, U35.141
A27: U4.B5, U35.139
A28: U4.A4, U35.138
A29: U4.B4, U35.137
A30: U4.A3, U35.136
A31: U4.B3, U35.134
BUZZER: SP1.2, U35.30
CFCLOCK: U1.4, U34.4, U35.179
CFCONFIG: SW1.1, U34.13, U35.121
CFDATA: U1.2, U34.2, U35.180
CFDONE: U34.9, U35.2
CFSTATUS: U1.8, U34.8, U35.60
CFTOCORE: U1.1, U35.177
CORETOHEADER: P3.3, U35.4
CTSA232: J2.A8, U3.23
CTSB232: J2.B8, U3.16
D0: U4.K13, U5.3, U11.18, U35.80
D1: U4.K12, U5.2, U11.17, U35.81
D2: U4.L13, U5.1, U11.16, U35.82
D3: U4.M13, U5.68, U11.15, U35.83
D4: U4.L12, U5.67, U11.14, U35.84
D5: U4.K11, U5.66, U11.13, U35.86
D6: U4.M12, U5.65, U11.12, U35.87
D7: U4.L11, U5.64, U11.11, U35.88
D8: U4.N13, U5.62, U12.18, U35.48
D9: U4.M11, U5.60, U12.17, U35.49
D10: U4.L10, U5.59, U12.16, U35.50
D11: U4.N12, U5.58, U12.15, U35.51
D12: U4.M10, U5.57, U12.14, U35.53
D13: U4.N11, U5.56, U12.13, U35.54
D14: U4.M9, U5.55, U12.12, U35.55
D15: U4.N10, U5.54, U12.11, U35.56
D16: U4.N9, U5.50, U7.18, U13.18, U19.13, U24.2, U33.95, U35.103
D17: U4.M8, U5.49, U7.17, U13.17, U19.14, U24.3, U33.94, U35.105
D18: U4.N8, U5.48, U7.16, U13.16, U19.15, U24.4, U33.93, U35.106
D19: U4.N7, U5.47, U7.15, U13.15, U19.17, U24.5, U33.92, U35.107
D20: U4.M7, U5.46, U7.14, U13.14, U19.18, U24.6, U33.91, U35.108
D21: U4.N6, U5.45, U7.13, U13.13, U19.19, U24.7, U33.90, U35.109
D22: U4.M6, U5.44, U7.12, U13.12, U19.20, U24.8, U33.88, U35.110
D23: U4.N5, U5.42, U7.11, U13.11, U19.21, U24.9, U33.87, U35.111
D24: U2.18, U4.M5, U5.40, U8.18, U14.18, U20.13, U25.2, U33.36, U35.38
D25: U2.17, U4.N4, U5.39, U8.17, U14.17, U20.14, U25.3, U33.37, U35.39
D26: U2.15, U4.N3, U5.38, U8.16, U14.16, U20.15, U25.4, U33.38, U35.40
D27: U2.13, U4.M4, U5.37, U8.15, U14.15, U20.17, U25.5, U33.39, U35.41
D28: U2.12, U4.N2, U5.36, U8.14, U14.14, U20.18, U25.6, U33.40, U35.43
D29: U2.11, U4.M3, U5.35, U8.13, U14.13, U20.19, U25.7, U33.41, U35.44
D30: U2.10, U4.L4, U5.34, U8.12, U14.12, U20.20, U25.8, U33.42, U35.45
D31: U2.9, U4.N1, U5.33, U8.11, U14.11, U20.21, U25.9, U33.43, U35.46
ETHINT: R20.2, U33.4, U35.14
EXPA0: J7.a12, J8.a12, J9.a12, J10.a12, RN7.1, RN12.9
EXPA1: J7.c12, J8.c12, J9.c12, J10.c12, RN7.2, RN12.10
EXPA2: J7.a13, J8.a13, J9.a13, J10.a13, RN7.3, RN12.11
EXPA3: J7.c13, J8.c13, J9.c13, J10.c13, RN7.4, RN12.12
EXPA4: J7.a14, J8.a14, J9.a14, J10.a14, RN7.5, RN12.13
EXPA5: J7.c14, J8.c14, J9.c14, J10.c14, RN7.6, RN12.14
EXPA6: J7.a15, J8.a15, J9.a15, J10.a15, RN7.7, RN12.15
EXPA7: J7.c15, J8.c15, J9.c15, J10.c15, RN7.8, RN12.16
EXPA8: J7.a16, J8.a16, J9.a16, J10.a16, RN8.1, RN13.9
EXPA9: J7.c16, J8.c16, J9.c16, J10.c16, RN8.2, RN13.10
EXPA10: J7.a17, J8.a17, J9.a17, J10.a17, RN8.3, RN13.11
EXPA11: J7.c17, J8.c17, J9.c17, J10.c17, RN8.4, RN13.12
EXPA12: J7.a18, J8.a18, J9.a18, J10.a18, RN8.5, RN13.13
EXPA13: J7.c18, J8.c18, J9.c18, J10.c18, RN8.6, RN13.14
EXPA14: J7.a19, J8.a19, J9.a19, J10.a19, RN8.7, RN13.15
EXPA15: J7.c19, J8.c19, J9.c19, J10.c19, RN8.8, RN13.16
EXPA16: J7.a20, J8.a20, J9.a20, J10.a20, RN9.1, RN14.9
EXPA17: J7.c20, J8.c20, J9.c20, J10.c20, RN9.2, RN14.10
EXPA18: J7.a21, J8.a21, J9.a21, J10.a21, RN9.3, RN14.11
EXPA19: J7.c21, J8.c21, J9.c21, J10.c21, RN9.4, RN14.12
EXPA20: J7.a22, J8.a22, J9.a22, J10.a22, RN9.5, RN14.13
EXPA21: J7.c22, J8.c22, J9.c22, J10.c22, RN9.6, RN14.14
EXPA22: J7.a23, J8.a23, J9.a23, J10.a23, RN9.7, RN14.15
EXPA23: J7.c23, J8.c23, J9.c23, J10.c23, RN9.8, RN14.16
EXPD16: J7.a1, J8.a1, J9.a1, J10.a1, RN5.1, RN10.16
EXPD17: J7.c1, J8.c1, J9.c1, J10.c1, RN5.2, RN10.15
EXPD18: J7.a2, J8.a2, J9.a2, J10.a2, RN5.3, RN10.14
EXPD19: J7.c2, J8.c2, J9.c2, J10.c2, RN5.4, RN10.13
EXPD20: J7.a3, J8.a3, J9.a3, J10.a3, RN5.5, RN10.12
EXPD21: J7.c3, J8.c3, J9.c3, J10.c3, RN5.6, RN10.11
EXPD22: J7.a4, J8.a4, J9.a4, J10.a4, RN5.7, RN10.10
EXPD23: J7.c4, J8.c4, J9.c4, J10.c4, RN5.8, RN10.9
EXPD24: J7.a5, J8.a5, J9.a5, J10.a5, RN6.1, RN11.16
EXPD25: J7.c5, J8.c5, J9.c5, J10.c5, RN6.2, RN11.15
EXPD26: J7.a6, J8.a6, J9.a6, J10.a6, RN6.3, RN11.14
EXPD27: J7.c6, J8.c6, J9.c6, J10.c6, RN6.4, RN11.13
EXPD28: J7.a7, J8.a7, J9.a7, J10.a7, RN6.5, RN11.12
EXPD29: J7.c7, J8.c7, J9.c7, J10.c7, RN6.6, RN11.11
EXPD30: J7.a8, J8.a8, J9.a8, J10.a8, RN6.7, RN11.10
EXPD31: J7.c8, J8.c8, J9.c8, J10.c8, RN6.8, RN11.9
EXPMPUCLK: J7.a25, J8.a25, J9.a25, J10.a25, U30.16
EXPR~W: J7.c26, J8.c26, J9.c26, J10.c26, U30.14
EXPSCLE0: J7.a9, U17.6
EXPSCLE1: J8.a9, U17.9
EXPSCLE2: J9.a9, U17.13
EXPSCLE3: J10.a9, U17.16
EXPSDAE0: J7.a10, U17.5
EXPSDAE1: J8.a10, U17.8
EXPSDAE2: J9.a10, U17.12
EXPSDAE3: J10.a10, U17.15
FC0: U4.D2, U35.113
FC1: U4.C1, U35.114
FC2: U4.D1, U35.115
GNDA: BT1.2, C1.2, C2.2, C3.2, C4.2, C5.2, C6.2, C7.2, C8.2, C9.2, C10.2, C14.2, C15.2, C16.2, C17.2, C18.2, C19.2, C20.2, C21.2, C22.2, C23.2, C24.2, C25.2, C26.2, C27.2, C28.2, C29.2, C30.2, C31.2, C32.2, C33.2, C34.2, C35.2, C36.2, C37.2, C38.2, C39.2, C40.2, C41.2, C42.2, C43.2, C44.2, C45.2, C46.2, C47.2, C48.2, C49.2, C50.2, C51.2, C52.2, C53.2, C54.2, C55.2, C56.2, C57.1, C58.1, C59.2, C60.2, C61.2, C62.2, C63.2, C64.2, C65.2, C66.2, C67.2, C68.2, C69.2, C70.2, C71.2, C72.2, C73.2, C74.2, C75.2, C76.2, C77.2, C78.2, CON1.2, CON1.3, H1.1, H2.1, H3.1, H4.1, H5.1, H6.1, H7.1, H8.1, H9.1, J1.4, J2.A4, J2.A5, J2.B4, J2.B5, J2.GND, J3.3, J4.3, J6.3, J7.a11, J7.a32, J8.a11, J8.a32, J9.a11, J9.a32, J10.a11, J10.a32, J11.13, J11.R8, J12.1, P1.1, P2.2, P2.19, P2.22, P2.24, P2.26, P2.30, P2.40, P3.2, P3.10, R2.1, R3.1, R6.1, R12.2, R17.1, R19.1, R20.1, R25.2, SW1.2, U1.10, U2.1, U2.14, U2.28, U2.40, U3.8, U4.C5, U4.C7, U4.C9, U4.E3, U4.E11, U4.F3, U4.G3, U4.G11, U4.J3, U4.J11, U4.L5, U4.L7, U4.L8, U4.L9, U5.5, U5.6, U5.7, U5.8, U5.9, U5.12, U5.14, U5.19, U5.30, U5.41, U5.51, U5.63, U6.7, U7.10, U8.10, U9.1, U9.39, U9.72, U10.1, U10.39, U10.72, U11.10, U12.10, U13.10, U14.10, U16.4, U17.1, U17.2, U17.3, U17.10, U18.4, U19.16, U20.16, U21.1, U22.1, U23.2, U24.10, U25.10, U26.10, U26.19, U27.10, U27.19, U28.10, U28.19, U29.10, U29.19, U30.10, U30.19, U31.10, U31.19, U32.7, U33.11, U33.12, U33.13, U33.14, U33.18, U33.19, U33.20, U33.21, U33.22, U33.23, U33.24, U33.25, U33.26, U33.27, U33.28, U33.44, U33.52, U33.64, U33.83, U33.86, U34.10, U35.10, U35.22, U35.32, U35.42, U35.52, U35.69, U35.85, U35.93, U35.104, U35.123, U35.124, U35.125, U35.135, U35.145, U35.155, U35.165, U35.176, U35.178, U35.197, U35.216, U35.232, X1.2
HEADERTOCF: P3.9, R27.2, U34.11
IDEIRQ: P2.31, R6.2, U35.31
LED: D1.2, U35.29
MPUCLK: U4.E1, U5.11, U30.4, U35.91, X1.3
unnamed: BT1.1, U18.3
unnamed: C9.1, U2.42, Y1.1
unnamed: C10.1, U2.41, Y1.2
unnamed: C11.1, U3.10
unnamed: C11.2, U3.12
unnamed: C12.1, U3.13
unnamed: C12.2, U3.14
unnamed: C13.2, U3.11
unnamed: C14.1, U3.15
unnamed: C40.1, CON1.1, U23.1
unnamed: C57.2, R18.2, U33.51, Y3.1
unnamed: C58.2, R18.1, U33.50, Y3.2
unnamed: C59.1, J11.R4
unnamed: C60.1, J11.R5
unnamed: D1.1, R3.2
unnamed: D2.1, P2.39
unnamed: D2.2, R7.2
unnamed: D3.1, R12.1
unnamed: D4.1, U33.63
unnamed: D4.2, R22.2
unnamed: J1.2, U2.44
unnamed: J1.3, U2.43
unnamed: J6.1, R16.1, R32.1
unnamed: J6.2, R14.1, R31.2
unnamed: J6.5, R15.1, R33.1
unnamed: J6.6, R13.1, R30.2
unnamed: J11.L1, R24.1
unnamed: J11.L2, U33.62
unnamed: J11.L3, U33.61
unnamed: J11.L4, R23.1
unnamed: J11.R1, U33.45
unnamed: J11.R2, U33.46
unnamed: J11.R3, R21.1, U33.59
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

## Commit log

2022-06-17 Added MAXI030 schematic, PCB and VHDL files
    TODO: Documentaiton...
    [Ethernet.kicad_sch, Ethernet.sch, ExpBuffers.kicad_sch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]
2022-06-18 Added expansion cards, with some doc updates
    Removed the old KiCAD 4 format files
    [Ethernet.sch, ExpBuffers.sch, Expansion.sch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]
2022-06-24 Updated the schematic
    Noticed it wasn't quite the one the final PCBs were based off.
2022-08-10 Added the MAXI030 bom, which somehow got left off
2025-10-16 Add a Makefile for building the VHDL glue with a remote Quartus

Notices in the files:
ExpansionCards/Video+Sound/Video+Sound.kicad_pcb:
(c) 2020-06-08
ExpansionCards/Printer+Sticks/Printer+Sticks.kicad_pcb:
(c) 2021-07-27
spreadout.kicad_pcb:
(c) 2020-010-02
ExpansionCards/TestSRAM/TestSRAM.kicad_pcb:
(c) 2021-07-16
